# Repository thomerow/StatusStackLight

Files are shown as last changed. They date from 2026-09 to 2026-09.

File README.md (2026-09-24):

# StatusStackLight

An industrial stack light with five lamps, driven by an ESP32-S3 in a 3D-printed base –
dimmable, blinking and pulsing, via an HTTP API and a web interface on the local network. In
everyday use it shows what the running Claude Code sessions are doing right now – directly on
the local network, or through a relay server from anywhere.

<p align="center">
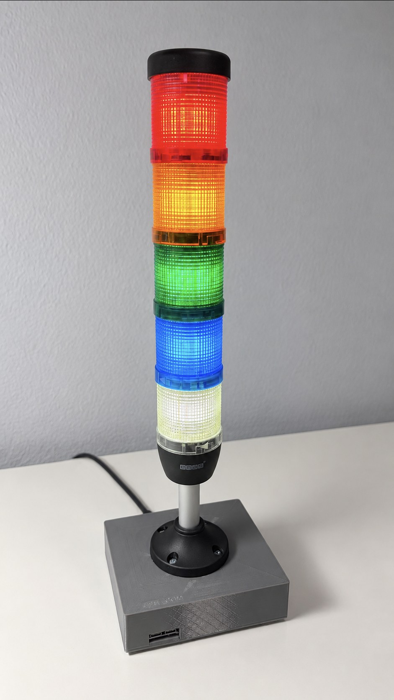
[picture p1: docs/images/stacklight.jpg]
The stack light with all five lamps lit on its 3D-printed base
  
</p>

## The four parts

| Folder | Contents |
|---|---|
| [`enclosure/`](enclosure/OpenSCAD/README.md) | Parametric base in OpenSCAD: carries the stack light and houses all the electronics. Print-ready STL files, print recommendations, assembly order. |
| [`firmware/`](firmware/README.md) | PlatformIO firmware for the ESP32-S3: PWM drive with effects, WiFi setup via captive portal, web interface, [HTTP API](firmware/API.md). |
| [`claude-code/`](claude-code/README.md) | PowerShell script that brings the state of Claude Code sessions to the stack light via hooks. |
| [`relay/`](relay/README.md) | Optional ASP.NET Core server between hooks and stack light: combines the sessions of several computers, the stack light polls it – no shared network needed. Admin interface for API keys, event rules and appearance. |

The parts build on each other but can also be used on their own: the firmware does not need
the base, the API is open to any client, not just the hook script, and the relay is only
needed when computer and stack light are not on the same network.

## Hardware

| Component | |
|---|---|
| Stack light | 5 lamps (white, blue, green, orange, red), 12 V LED modules, flange with 4 × M4 on a 55 mm bolt circle |
| Microcontroller | ESP32-S3 DevKitC-1 **N16R8** (16 MB flash, 8 MB octal PSRAM) |
| Driver | 8-channel MOSFET module, active LOW; 5 channels used |
| Power | USB-C PD trigger board (requests 12 V) → Mini560 buck → 3.3 V into the ESP32's 3V3 pin |
| Base | 138.8 × 120.8 × 35.8 mm, PETG or PLA+, heat-set inserts 4 × M3 and 4 × M4 |

<p align="center">
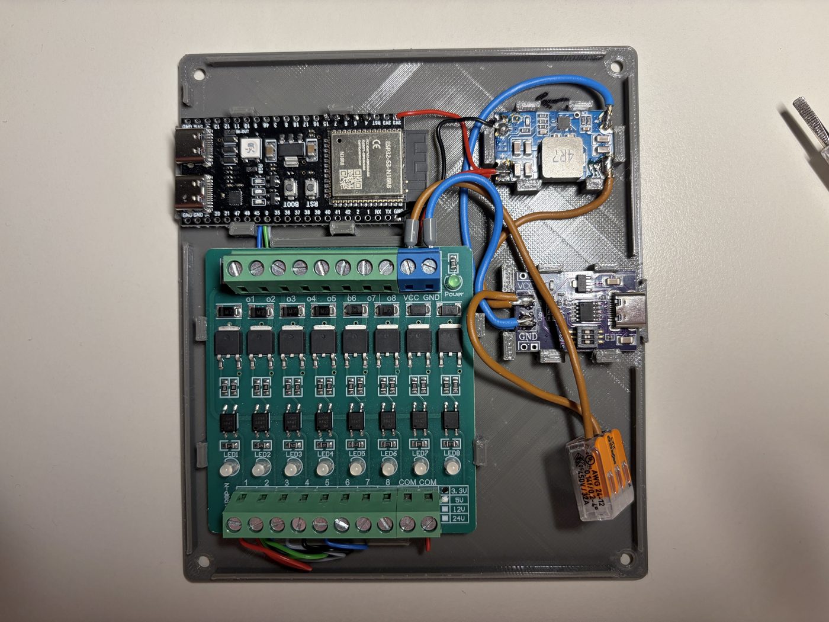
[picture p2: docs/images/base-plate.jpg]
The populated base plate seen from above: 8-channel MOSFET module, ESP32-S3, Mini560 and PD trigger board, each held by clips
  
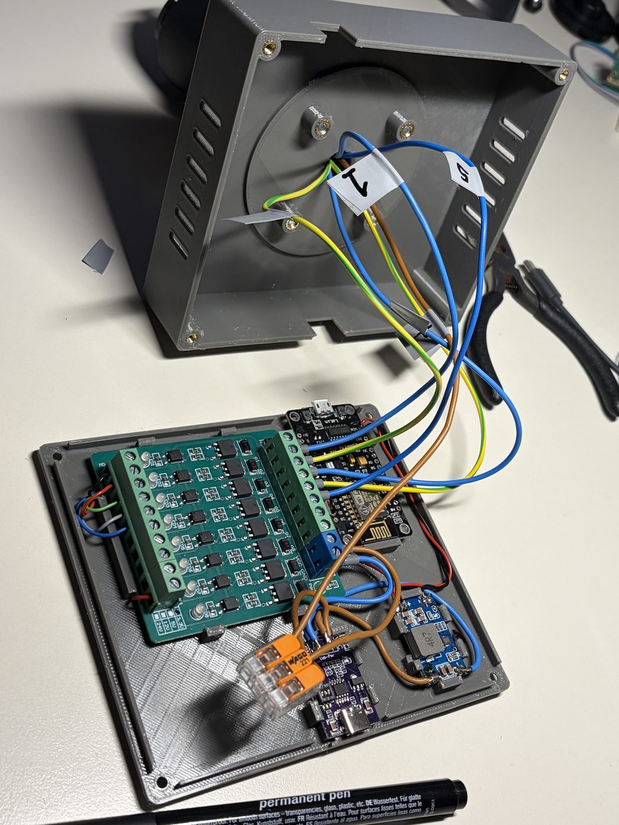
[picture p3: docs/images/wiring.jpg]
The main body standing on its lid with the lamp cables coming through the feed-through, next to it the populated base plate
  
  <br><em>Everything sits on the base plate, held by printed clips – no screws. The five lamp
  cables come through the feed-through in the lid.</em>
</p>

Pin assignment, dimensions and details are in the READMEs of
[`enclosure/`](enclosure/OpenSCAD/README.md) and [`firmware/`](firmware/README.md).

## Quick start

1. **Print:** `enclosure/OpenSCAD/body.stl` and `base.stl`, support-free, see the
   [print recommendations](enclosure/OpenSCAD/README.md#print-recommendations).
2. **Assemble and wire** following the
   [assembly order](enclosure/OpenSCAD/README.md#assembly-order).
3. **Flash:** in `firmware/` with [PlatformIO](https://platformio.org/) `pio run -t upload`,
   see [Building and flashing](firmware/README.md#building-and-flashing).
4. **Set up WiFi:** on first start the device opens the access point
   `StatusStackLight-XXXX`; the setup page appears by itself, see
   [WiFi setup](firmware/README.md#wifi-setup).
5. **Try it out:** `http://statusstacklight.local/` in the browser – every lamp can be
   switched there individually with all its parameters.
6. Optional: set up the **Claude Code display**, see [`claude-code/`](claude-code/README.md).
7. Optional: run the **relay** on a server, see [`relay/`](relay/README.md), and switch the
   stack light and the hook script to relay mode.

## License

[MIT](LICENSE) – for firmware, scripts, relay, enclosure model and documentation.

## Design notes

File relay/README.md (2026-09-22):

# StatusStackLight – Relay

A small ASP.NET Core service that sits between the Claude Code hooks and the stack light, so
computer and stack light no longer need to be on the same network:

```
 Claude Code ──hook──▶ stacklight.ps1 ──POST /api/v1/events──▶ ┌────────┐
 (any number of                                                │ relay  │ ◀── admin interface
  computers)                                                   └────────┘     (browser)
                                                                   ▲
 stack light ──────────── GET /api/v1/lamps (long poll) ───────────┘
```

- The **hook script** reports every event (`SessionStart`, `Approval`, `Stop`, …) with its
  session ID – in [relay mode](../claude-code/README.md#relay-mode).
- The **relay** keeps the sessions of all computers and turns them into the image of the five
  lamps: which state wins, when green falls back to white, when a crashed session is
  forgotten, when the warning flash ends.
- The **stack light** fetches that image by long polling – in
  [relay mode](../firmware/README.md#relay-mode). A change arrives within a fraction of a
  second; while nothing happens, there is one request every 25 seconds.
- The **admin interface** sets what each event does and how each state looks, and manages
  the API keys. Out of the box it does exactly what the script does in LAN mode.

The relay needs no inbound connection to your home network – the stack light always calls
out.

## Admin interface

| Page | |
|---|---|
| Dashboard | what the stack light shows right now (animated), open sessions, polling stack lights, test events |
| Display | per state (ready, done, working, asking, waiting, error, warning flash): which lamps, effect, brightness, rate, duty cycle – with a live preview |
| Events | per hook event: which session state it sets, whether it sets or clears the error, an optional condition, warning flash |
| Settings | priority of the main states, done → ready after, forget sessions after, flash duration, long poll duration |
| Keys | create, rename, delete API keys |

Every page has *Reset to defaults*. The defaults live in one place,
[`Domain/Defaults.cs`](src/StatusStackLight.Relay/Domain/Defaults.cs).

**Keys** have a role: *lamp* keys may only fetch the display, *client* keys may only report
events. Give every stack light and every computer a key of its own – then a lost laptop is
one click away from being locked out. A key is shown exactly once when it is created; the
relay only stores its SHA-256 hash.

**The admin password** is set on the server, never over the web: an admin interface on the
internet that lets its first visitor choose the password is an open door until someone gets
there first. Login attempts are limited to ten per minute and address.

## Trying it locally

Requires the [.NET 10 SDK](https://dotnet.microsoft.com/download).

```powershell
cd relay/src/StatusStackLight.Relay
dotnet run -- set-password        # once: the admin password
dotnet run                        # http://localhost:5080
```

Create a *client* key and a *lamp* key under **Keys**. Then:

- **Hook script:** `setx STACKLIGHT_RELAY_URL "http://<this computer's IP>:5080"` and
  `setx STACKLIGHT_RELAY_KEY "ssl_…"` (the client key), restart Claude Code.
- **Stack light:** in its web interface under *Relay*: address
  `http://<this computer's IP>:5080`, the lamp key, relay mode on.

On Windows the firewall asks the first time whether `StatusStackLight.Relay.exe` may accept
connections – allow it for private networks, otherwise the stack light cannot reach it.

Data (database and login keys) ends up in `App_Data/` next to the project.

## Running it on a server

The following assumes a Linux server with nginx and a host name, e.g. `relay.example.org`.

**1. Publish** – self-contained, so the server needs no .NET runtime:

```bash
dotnet publish src/StatusStackLight.Relay -c Release -r linux-x64 --self-contained -o publish
```

For an ARM server (e.g. a Raspberry Pi): `-r linux-arm64`.

**2. Install:**

```bash
sudo useradd --system --no-create-home --shell /usr/sbin/nologin statusstacklight
sudo mkdir -p /opt/statusstacklight-relay
sudo rsync -a --delete publish/ /opt/statusstacklight-relay/     # or scp
sudo chmod +x /opt/statusstacklight-relay/StatusStackLight.Relay

sudo cp deploy/statusstacklight-relay.service /etc/systemd/system/
sudo systemctl daemon-reload
sudo systemctl enable --now statusstacklight-relay
```

**3. Set the admin password** – as the service user, with the same data directory as the
service:

```bash
cd /opt/statusstacklight-relay
sudo -u statusstacklight env DataDirectory=/var/lib/statusstacklight-relay \
     ./StatusStackLight.Relay set-password
```

The command can be run again at any time to change the password; logins stay valid.

**4. nginx with HTTPS:** adapt [`deploy/nginx.conf.example`](deploy/nginx.conf.example),
then `sudo certbot --nginx -d relay.example.org`. Important for long polling:
`proxy_read_timeout` must be longer than the relay's long poll duration (25 s by default);
the example uses 60 s.

The address for hook script and stack light is then `https://relay.example.org`.

**Updates:** publish again, copy over, `sudo systemctl restart statusstacklight-relay`. The
database is migrated automatically at startup. Stack lights reconnect by themselves within a
few seconds; sessions are held in memory only and come back with each session's next hook.

### Without nginx

The relay can also listen on a port directly: set `Urls=http://0.0.0.0:5080` in the systemd
unit and open the port in the firewall. **Then the API keys and the admin password travel over
the internet in plain text** – only do that for a test, or give Kestrel a certificate of its
own (see the ASP.NET Core documentation on `Kestrel:Certificates`).

### Configuration

Environment variables (or `appsettings.json`):

| Name | Default | |
|---|---|---|
| `Urls` | `http://*:5080` | address and port to listen on |
| `DataDirectory` | `App_Data` | database `relay.db` and the key ring for the login cookie `keys/`; relative to the working directory |
| `PathBase` | – | sub-path when served under e.g. `https://example.org/stacklight/` |

**Backup:** the data directory is all there is. Losing `keys/` only logs you out; losing
`relay.db` loses the API keys, the configuration and the admin password.

## API

For stack lights and scripts – see **[API.md](API.md)**.

## Development

```powershell
cd relay
dotnet test                                   # domain logic, API, admin pages
dotnet tool restore                           # once, for dotnet-ef
dotnet dotnet-ef migrations add <Name> -p src/StatusStackLight.Relay -o Data/Migrations
```

```
src/StatusStackLight.Relay/
  Domain/     display logic: sessions, event rules, lamp image, defaults – no ASP.NET
  Data/       SQLite via EF Core: API keys and the configuration (as JSON per section)
  Api/        JSON API, API key authentication, stack light registry
  Pages/      admin interface (Razor Pages)
  Services/   timer for time-driven transitions, admin password
  wwwroot/    CSS and the small script for preview and dashboard
tests/        xUnit: engine, validation, API, admin pages
deploy/       systemd unit, nginx example
```

**How the image comes about** – a port of `Get-MainState` and `Get-Lamps` from
[`stacklight.ps1`](../claude-code/stacklight.ps1):

1. Every event changes its session according to its rule (state, error flag).
2. Of the sessions, exactly one main state wins by priority: waiting > asking > working >
   done > ready. Done only counts while it is fresh (5 min); after that the session counts as
   ready. Sessions without events for an hour are forgotten.
3. On top: error (if any session has one), then the warning flash (for 1.2 s after `Danger`).
4. Lamps that are off still carry the parameters of their state, so the stack light's web
   interface shows sensible values.

The image carries a **version** that only changes when the image changes. A stack light
polls with the version it shows and gets an answer as soon as there is a different one –
a burst of events that ends where it started costs it nothing.

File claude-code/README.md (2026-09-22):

# StatusStackLight – Claude Code session display

`stacklight.ps1` shows on the stack light what the running
[Claude Code](https://claude.com/claude-code) sessions are doing right now: whether Claude
is working, is done, has a question or is waiting for an approval. The script hooks into
Claude Code and drives the stack light through the [firmware's HTTP API](../firmware/API.md) –
or, in [relay mode](#relay-mode), through a relay server the stack light polls.

## What the stack light shows

| Lamp | State | Appearance |
|---|---|---|
| white | ready – session open, nothing going on | breathes very slowly, 0.15 Hz, up to 30 % |
| green | done – just finished | steady, 45 %, for five minutes |
| blue | working | pulsing, 0.3 Hz, 70 % |
| orange | a question for you | steady, 40 % |
| orange | waiting for an approval | blinking, 1.2 Hz, 40 % |
| red | error | steady, 100 %, latched until the next prompt |
| red | dangerous command (`rm -rf`, `git push --force`, …) | short flash, 6 Hz, on top of the other state |

Exactly one of ready/done/working/question/approval is lit (priority from right to left);
red sits on top independently.

## Setup

**Requirements:** Windows with [PowerShell 7](https://github.com/PowerShell/PowerShell)
(`pwsh.exe`) and a stack light running the firmware from this repo on the same network.

1. **Address of the stack light.** The script talks to it at `http://statusstacklight`. If
   your network does not resolve that name, set the environment variable `STACKLIGHT_URL`,
   for example to `http://statusstacklight.local` or `http://192.168.178.72`.
2. **Add the hooks.** Copy the `hooks` block from [`hooks.example.json`](hooks.example.json)
   into `~/.claude/settings.json`. In every entry, replace the placeholder
   `C:\path\to\StatusStackLight\claude-code\stacklight.ps1` with the actual path, and if
   PowerShell 7 lives elsewhere, `command` as well.
3. **Try it out** without waiting for a hook:

   ```powershell
   $s = 'C:\path\to\StatusStackLight\claude-code\stacklight.ps1'
   & $s -Event Status      # shows what the stack light should show, without switching anything
   & $s -Event SelfTest    # the firmware's channel sweep, then back to the actual state
   & $s -Event AllOff
   ```

The script keeps its state under `~/.claude/stacklight/` (one file per session, plus
`_timer.json` and `_error.log`). It always exits with exit code 0 – an unreachable stack
light never holds up Claude Code; errors end up in `_error.log`.

## Relay mode

Without a relay, computer and stack light must be on the same network. With the
[relay](../relay/README.md), a small server anywhere on the internet, they need not: the script
reports its events there, and the stack light fetches the result. Sessions on several
computers then show up on the same stack light.

Set two environment variables for the user that runs Claude Code, with a key of the role
*client* from the relay's admin interface, and restart Claude Code:

```powershell
setx STACKLIGHT_RELAY_URL "https://relay.example.org"
setx STACKLIGHT_RELAY_KEY "ssl_…"
```

The hooks stay exactly as they are. As soon as both variables are set, the script sends every
event as one `POST /api/v1/events` to the relay instead of switching the stack light itself;
without them it works in LAN mode as before. `-RelayUrl` and `-RelayKey` override the
variables, for example to try it out:

```powershell
& $s -Event Status -RelayUrl https://relay.example.org -RelayKey ssl_…
```

In relay mode, the appearance and the event rules are set in the relay's admin interface –
the `$Display` table in the script only applies to LAN mode. Two things stay local:

- **The dangerous-command check.** For `Danger` the script checks the command text itself and
  only reports `Danger` – the command never leaves the computer.
- **The `ToolDone` shortcut.** `PostToolUse` fires after every tool call; the script only
  reports it while the session is waiting or asking, the condition of the relay's default
  rule. For this it keeps its session files as before.

`SelfTest` talks to the stack light directly and only works in LAN mode. `AllOff` makes the
relay forget all sessions, including those of other computers.

## How it works

The hooks deliver **events**, the stack light shows a **state**. Every session stores its
state as a file under `~/.claude/stacklight/`; from these the script computes what the lamps
show and sets it in **one** `POST /api/lamps` – completely on every event, even if nothing
has changed. That way the next hook heals any deviation, whether caused by a restart of the
stack light, the web interface or curl. Several parallel sessions therefore do not switch
each other off, and a crashed session is forgotten after an hour without events.

| Hook | Matcher | Event in the script |
|---|---|---|
| `SessionStart` | – | `SessionStart` |
| `UserPromptSubmit` | – | `UserPromptSubmit` |
| `Notification` | `permission_prompt` | `Approval` |
| `Notification` | `elicitation_dialog\|elicitation_url_dialog\|agent_needs_input` | `Question` |
| `PreToolUse` | `ExitPlanMode` | `Approval` |
| `PreToolUse` | `AskUserQuestion` | `Question` |
| `PreToolUse` | `Bash`, with `if` on dangerous commands | `Danger` |
| `PostToolUse` | `*` | `ToolDone` |
| `Stop` / `StopFailure` | – | `Stop` / `StopFailure` |
| `SessionEnd` | – | `SessionEnd` |

The script still accepts `Freigabe` and `Rueckfrage`, the former German names of `Approval`
and `Question`, so older hook configurations keep working.

**Red only when it matters.** `PostToolUseFailure` is deliberately not wired up, although the
script understands it as `-Event ToolFailure`. Failed tool calls are part of normal work – a
search without a match, a test that is meant to fail – and Claude usually handles them by
itself. Red for each of them would come so often that you stop looking, and then it is
overlooked in the one case that counts. Red stays reserved for a response that ended in an
error (`StopFailure`) and for the warning flash.

**Orange only when Claude needs you.** The Notification hook has matchers on the
notification type: `permission_prompt` is an approval (blinking), `elicitation_dialog`,
`elicitation_url_dialog` and `agent_needs_input` are questions (steady). The idle notice
after a minute without input (`idle_prompt`) is deliberately left out – it would turn every
green into orange after 60 s. In addition, the tools `ExitPlanMode` (approval) and
`AskUserQuestion` (question) trigger directly via `PreToolUse`. The distinction is made
through separate hook entries with the events `Approval` and `Question`, not through fields
of the hook input: their structure is not documented for Notification.

A question that Claude simply asks as text at the end of its response cannot be detected by
the hooks – then the stack light shows green, as for every finished response.

**Orange goes off again** as soon as the approved tool has run or the question has been
answered: `PostToolUse` calls the script with `ToolDone`, and it switches back to blue.
Without that, orange would stay lit until the end of the response, because an approval is
not a new prompt. Limitation: Claude Code does not report a moment of "approval granted" –
during a long build it therefore blinks until the approved command has finished.
`PostToolUse` fires after every tool call; if the session is not waiting, the script exits
immediately without a request to the stack light.

**Green falls back to white after five minutes** – "freshly done" is different information
from "has been sitting there a while". Since no hook may fire for a long time after that,
`Stop` starts a hidden straggler that waits out the time and recomputes once. Only one ever
runs; a new `Stop` ends the previous one.

**Brightness:** White is by far the brightest lamp and needs much less percent to look
equally bright – undimmed it is unbearable as a steady light. When breathing, the percentage
is the peak: the breath runs from 0 up to there, and due to gamma correction the lower third
is practically dark. That is why the peak at 30 % is well above what white would need as a
steady light. Orange at full brightness is glaring up close and therefore runs dimmed; the
attention comes from the blinking, not from the brightness. All values are in the
`$Display` table at the top of the script.

**Warning flash only for real matches.** The `if` conditions in the `PreToolUse` hook
(`Bash(rm -rf *)` etc.) are only a rough pre-filter: commands that Claude Code cannot parse
cleanly – loops, `$(…)`, heredocs – are let through to be safe; even
`for i in 1; do echo "$(echo harmless)"; done` passes the pre-filter. The script therefore
checks the actual command text once more itself.

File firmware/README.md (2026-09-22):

# StatusStackLight – Firmware (ESP32-S3)

Firmware for the 5-lamp stack light. It provides an HTTP JSON API for driving the lamps and
a web interface that lets you play through every parameter of each lamp individually.

The enclosure and mechanics live in [`../enclosure`](../enclosure/OpenSCAD/README.md), the
display of Claude Code sessions in [`../claude-code`](../claude-code/README.md). The
[README in the root directory](../README.md) gives an overview of the whole project.

## What the lamps can do

Each lamp has a master switch, a brightness and a timing behaviour:

| Field | Range | Meaning |
|---|---|---|
| `on` | `true` / `false` | master switch |
| `brightness` | 0…100 % | peak brightness, gamma corrected |
| `effect` | `steady`, `blink`, `pulse` | constant / hard blinking / soft pulsing |
| `frequency` | 0.1…20.0 Hz | rate for `blink` and `pulse` |
| `duty` | 1…99 % | `blink` only: share of the period during which the lamp is lit |

`on` is deliberately separate from the effect. Turn a blinking lamp off and on again and you
get it back blinking – brightness and effect survive being switched off.

Several lamps with the same frequency blink in sync; the effect engine uses a common time
base for all five.

How to set these fields is described in [API.md](API.md).

## Hardware

| Item | Value |
|---|---|
| Board | ESP32-S3 DevKitC-1, **N16R8** (16 MB flash, 8 MB octal PSRAM) |
| Driver | 8-channel MOSFET module, low side, **active LOW** (GPIO to ground = lamp on) |
| Lamps | 12 V LED modules |
| Power | USB-C PD trigger board (12 V) → Mini560 buck → 3.3 V into the ESP32's 3V3 pin |

### Channel mapping

| Channel | GPIO | Colour | API ID |
|---|---|---|---|
| 1 | 4 | white | `white` |
| 2 | 5 | blue | `blue` |
| 3 | 6 | green | `green` |
| 4 | 7 | orange | `orange` |
| 5 | 15 | red | `red` |

This mapping was verified against the assembled stack light on 2026-09-21.

After rewiring or replacing a lamp, it can be checked again with the
[channel sweep](#diagnostics). If it no longer matches, swap the lines of the `LAMPS[]`
table in `include/config.h` – nothing else.

## WiFi setup

Credentials are stored in NVS, not in the source. If the device finds none there – freshly
flashed, on a different board or after `POST /api/reset` – it opens an open access point
itself:

1. The access point **`StatusStackLight-XXXX`** appears in the WiFi list (`XXXX` = the last
   two bytes of the MAC address, also printed on the serial console).
2. Connect – the setup page opens by itself as a captive portal. If not:
   `http://192.168.4.1/setup`.
3. Choose a network, enter the password, save. The device **tries the credentials first**
   and only stores them if the connection succeeds – a typo does not lock you out. That is
   why the response takes up to 20 seconds.
4. After that it is reachable at **`http://statusstacklight.local/`** (or at the IP the
   setup page reports – Android does not resolve `.local` reliably).

If the connection drops during operation, the device keeps retrying on its own; the lamps
keep showing their last state meanwhile. If it stays unsuccessful for more than two minutes,
the setup AP opens again. The API is then reachable at the AP address; changes to the lamps
are stored but only shown after the next connection – until then, orange pulses (see
below).

### Boot display

When plugged in, the stack light shows how far along it is instead of showing the stored
lamp state right away:

| Display | Meaning |
|---|---|
| blue pulsing (1 Hz) | connecting to the stored WiFi network |
| green lit for one second, then briefly dark | connected – then the stored lamp state appears |
| orange pulsing slowly | setup AP open: no WiFi stored or none reachable |
| red pulsing slowly, dim | relay mode: no contact to the relay for a minute, see [Relay mode](#relay-mode) |

Orange stays until a WiFi network has been entered via the setup AP; during the connection
attempt blue pulses again, and on success the green signal follows. Blue deliberately pulses
faster than "Claude is working" (0.3 Hz). If the connection only drops briefly during
operation, no display appears – the Claude status stays visible. Rate, flash duration and
brightness are set in `config.h` under `DISPLAY_*`.

## Relay mode

Normally the stack light waits on the local network for the hook script to switch it. In
**relay mode** it fetches its state itself from a [relay server](../relay/README.md) on the
internet instead – then the computers running Claude Code need not be on the same network,
and several of them can feed the same stack light.

Set it up at the bottom of the web interface under **Relay**: switch on relay mode, enter the
relay's address (for example `https://relay.example.org` or `http://192.168.178.10:5080`) and
a key with the role *lamp* from the relay's admin interface, save. The key is stored in NVS
(namespace `ssl-relay`) and never shown again; to keep it, leave the field empty.

- **Long polling:** the stack light asks the relay for the current image and names the
  version it shows. The relay holds the request until something changes, at the latest
  25 seconds (`RELAY_WAIT_S`). A change thus arrives within a fraction of a second, and while
  nothing happens there is one request every 25 seconds.
- **HTTPS** works with certificates from Let's Encrypt: the firmware trusts the roots ISRG
  Root X1 and X2 (`include/relay_ca.h`). For another CA, add its root certificate there.
  Without TLS, the key travels over the network in plain text.
- **The local API stays usable** – handy for trying things out. What is set locally stays
  until the relay's next change overwrites it. The web interface shows a banner in relay mode.
- **Without contact to the relay** for more than a minute (`RELAY_LOST_AFTER_MS`), **red
  pulses slowly and dimly** – the display is out of date, nothing is broken. Retries back off
  from 2 to 30 seconds; as soon as the relay answers, its image appears. The web interface
  names the last error (wrong key, address unreachable, …).

Over the API: `POST /api/config/relay`, see [API.md](API.md#post-apiconfigrelay).

## Diagnostics

At the bottom of the web interface: **Channel sweep**. It turns channels 1 to 5 on one at a
time for one second each and reports on the serial console which colour is expected – the
quickest way to see each channel on its own after replacing a lamp or when a loose contact
is suspected:

```
[sweep] channel 1  GPIO  4  expected: white
[sweep] channel 2  GPIO  5  expected: blue
...
```

Afterwards the previous state is restored. Also available via the API: `GET /api/sweep`.

If a channel misbehaves:

- **One lamp stays dark while the others work** – the fault is behind the GPIO. To narrow it
  down, measure at the MOSFET output while the sweep is on that channel.
- **The wrong lamp lights up** – swap the lines in `LAMPS[]` in `include/config.h`.
- **The stack light flashes briefly while booting** – the MOSFET module lacks pull-ups on its
  control inputs; add 10 kΩ to 3.3 V on each. The firmware drives the GPIOs to the off level
  first thing, but cannot bridge the time before that.
- **Everything switches exactly the wrong way round** – `LAMP_ACTIVE_LOW = false` in
  `config.h`.

## API

The complete description of all endpoints with requests, real responses, error codes and
examples in curl and PowerShell is in **[API.md](API.md)**.

A quick start:

```bash
curl http://statusstacklight.local/api/status                     # everything at a glance
curl 'http://statusstacklight.local/api/lamps/red/on?brightness=50' # turn red on
curl -X PATCH http://statusstacklight.local/api/lamps/orange \
     -H 'Content-Type: application/json' -d '{"effect":"blink","frequency":2}'
```

Invalid values are rejected with `400` and a plain-text message instead of being silently
clamped – a silently halved brightness sends you looking in the wrong place when debugging.

## Building and flashing

```powershell
pio run                 # build
pio run -t upload       # build and flash
pio device monitor      # serial console, 115200 baud
```

Two environments, depending on which USB-C port of the DevKitC-1 you use (labelled `USB` and
`COM` on the enclosure lid):

| Environment | Port | |
|---|---|---|
| `uart` (default) | **COM** | Recommended. The port survives reset and flashing, and you also see the output of the ROM bootloader. |
| `usb` | **USB** | Native USB port. Works, but the COM port disappears on every reset. |

```powershell
pio run -e usb -t upload
```

The first build downloads the platform and the Xtensa toolchain – that takes a while and
needs internet access.

**Power while flashing:** The Mini560 feeds 3.3 V directly into the 3V3 pin, bypassing the
board's voltage regulator. If USB is plugged in as well, two sources drive the same rail –
Espressif explicitly calls the two supply paths "mutually exclusive". For a short flash this
usually works in practice; the clean way is to disconnect the 3.3 V line first (ground may
stay). The board is a clone with a CH343 instead of a CP2102N, so protection diodes on the
USB ports are not guaranteed.

### Two things that are this way on purpose

**`build_dir` points outside the project** (`C:/pio/StatusStackLight`). For one, non-ASCII
characters in paths are explicitly unsupported by PlatformIO, and a build directory outside
the project keeps that independent of where the project lives. For another, `.pio/build` is
around ten thousand files – in a Dropbox folder that means constant syncing and now and then
a locked file in the middle of a build.

**`board_build.arduino.memory_type = qio_opi`** matches the ESP32-S3-**WROOM-1** N16R8 (quad
flash, octal PSRAM). The similarly named WROOM-**2** N16R8**V** has 1.8 V octal flash and
would need `opi_opi` plus `flash_mode = dout` – otherwise the board does not even boot. When
in doubt, read the marking on the module. The startup banner prints the PSRAM size; if it
shows zero bytes instead of about 8 MB, the setting is wrong.

### If the build fails

**`ModuleNotFoundError: No module named 'intelhex'`** while creating `bootloader.bin`: the
bundled esptool 4.9 needs this Python package, but PlatformIO's own environment does not
include it. Install it once:

```powershell
& "$env:USERPROFILE\.platformio\penv\Scripts\python.exe" -m pip install intelhex
```

**Strange errors when opening files**: first suspect non-ASCII characters in the path (see
`build_dir` above) before searching the source.

## Structure

```
API.md                  HTTP API: all endpoints with examples
platformio.ini          board, environments, libraries
include/config.h        pins, colours, limits, defaults  <- adjust things here
scripts/embed_web.py    pre-build: web/*.html -> include/web_assets.h (gzip)
web/index.html          control page (source)
web/setup.html          WiFi setup page (source)
src/main.cpp            setup/loop
src/lamps.*             LEDC, effect engine, gamma, inversion, system displays
src/lamp_state.*        state of a lamp, validation, JSON
src/lamp_store.*        last lamp state in NVS, survives restarts
src/wifi_portal.*       credentials, station connection, setup AP, captive portal
src/relay_client.*      relay mode: long polling in its own task
include/relay_ca.h      root certificates for HTTPS to the relay
src/api_server.*        HTTP routes
```

The web interface is gzipped during the build and embedded into the firmware image as a byte
array. The HTML files thus remain normal, editable files, while a single upload step is
still enough – no separate flashing of a file system that you are guaranteed to forget after
an OTA. `include/web_assets.h` is generated and listed in `.gitignore`.

### Why the effects run in their own task

The LEDC base frequency stays constant at 1 kHz; the effects only modulate the duty cycle.
That is handled by a FreeRTOS task at 100 Hz on **core 0**, while the web server runs in the
Arduino loop on core 1. This separation is why the synchronous `WebServer` from the Arduino
core is good enough: not even a hanging HTTP client can make the blinking stutter. This
spares the project a dependency on ESPAsyncWebServer and AsyncTCP along with their version
traps.

### State across restarts

The firmware remembers the state of all five lamps in NVS (namespace `ssl-lampen`, separate
from the WiFi credentials – `/api/reset` leaves it alone) and restores it at startup, before
the effect task starts. Without that, the stack light would stay dark after a power cut,
restart or flash until the next hook happens to send the target state – and if Claude is
waiting for input, none fires.

It only writes on a real change and only after 2 s of quiet (`STORE_DELAY_MS`). The hook
script sends the complete state on every event, mostly unchanged – that does not trigger a
write. A slider dragged in the web interface results in one write instead of twenty, and the
warning flash is over before it reaches the flash.

The restored state may be outdated – say, blue pulsing from a session that ended during the
power cut. The next hook corrects that.

The NVS namespaces (`ssl-lampen`, `ssl-wlan`) and keys keep their original German names, so
devices keep their stored state and credentials across firmware updates. The relay settings
live in `ssl-relay`.

### PWM base frequency

Fixed at **1 kHz** (`PWM_BASE_FREQUENCY` in `config.h`), not changeable at runtime. There is
little headroom anyway: the MOSFET module manages about 2 kHz because its gates are
discharged through a 10 kΩ pull-down, which makes turn-off sluggish. The ESP32 would not be
the limit – its LEDC block would reach 19.5 kHz at 12 bits.

Not to be confused with a lamp's `frequency` field: that is the blink or pulse rate
(0.1–20 Hz) and has nothing to do with the PWM carrier frequency.

## Displaying Claude Code sessions

Through hooks, the stack light shows the state of running Claude Code sessions. The script,
hook configuration and display scheme are in [`../claude-code`](../claude-code/README.md);
across networks through the relay, see [Relay mode](#relay-mode).

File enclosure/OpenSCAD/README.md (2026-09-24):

# StatusStackLight – Enclosure (OpenSCAD)

Parametric, 3D-printable enclosure that carries an industrial stack light and houses the
electronics: ESP32-S3 DevKitC-1 (N16R8), 8-channel MOSFET module, Mini560 buck converter
(12 V → 3.3 V) and a USB-C PD trigger board that requests 12 V from the power supply.

**The stack light has 5 lamps.** So only 5 of the 8 MOSFET channels are used; the other
three are deliberately left free. The 8-channel module is in there anyway because it was on
hand – at 68 × 72 × 16 mm it is the largest component and thus determines both the inner
dimensions and the inner height of the enclosure. If you want a smaller box, start there,
not with the microcontroller.

**Stage 1: two parts** – main body with integrated lid + removable base plate.

| File | Contents |
|---|---|
| `statusstacklight_enclosure.scad` | complete model, all dimensions as variables at the top of the file |
| `render.ps1` | generates STLs and preview images from the command line |
| `body.stl` / `base.stl` | exported printable parts (from the current parameters) |
| `preview/` | rendered previews |

Current outer dimensions: **138.8 × 120.8 × 35.8 mm** (interior 134 × 116 × 31 mm).

## Design principles

* **Coordinates:** `x = 0…inner_x` (left→right), `y = 0…inner_y` (front→back), `z = 0` is
  the parting plane = top of the base plate. All layout positions are given in these inner
  coordinates.
* **The base plate carries all the electronics.** It is populated outside the enclosure and
  then slid in vertically from below.
* **Flat top.** The lid is completely smooth on the outside – only the four M4 holes and the
  cable feed-through. A raised centering ring around the stack light base is still in the
  model as `light_centering_ring`, but **disabled**: the main body is printed standing on the
  lid, so the ring would be the only thing resting on the print bed, and the whole remaining
  lid surface would hang 1.2 mm in the air. The flange is centred by the four M4 screws on
  the 55 mm bolt circle anyway.
* **No screws for the boards.** Each board sits on four support pads; along one edge there
  are two rigid support ledges, along the opposite edge two springy snap clips with a 45°
  lead-in chamfer. Slide the board at an angle under the rigid side, press down on the
  opposite side – it snaps in.
* **Closure:** 4 corner bosses with M3 heat-set inserts (Ø 4.0 × 6 mm), M3 countersunk
  screws from below. The countersinks are **conical** (90° per DIN 7991), so the head rests
  flat on the cone flank instead of on an edge. The depth is computed from
  `countersink_angle` and `countersink_d` and not set separately – otherwise the cone no
  longer matches the screw head. A short cylindrical lead-in (`countersink_lead`, 0.3 mm) at
  the outer surface absorbs the elephant's foot of the first layer; the head thus sits about
  0.4 mm below the surface. With a 2.4 mm floor, 0.7 mm of material remains below the
  countersink – the model computes this and warns if it gets too thin.

### USB-C PD trigger board – strain relief

The port sits in the middle of a 20 mm edge and passes through the middle of the front
wall:

* The wall opening (13.5 × 7.5 mm) is **open downwards to the parting plane**, so the
  populated base plate slides in without collisions – and it prints without a bridge.
* A **connector collar** on the base plate fills the slot below the opening again and forms
  the lower edge of the visible opening.
* The port **protrudes 1 mm beyond the board edge** and thus dips into the wall opening
  itself.
* An **outer recess** (17 mm wide, 1.2 mm deep) thins the wall in front of the port.
  Together with the protrusion, only **0.2 mm of wall** remains in front of the port mouth –
  the plug seats practically flush and its full length engages. The model checks this at
  compile time (`usbc_gap`); the recess must not exceed `wall − usbc_protrusion`.
* **Force flow:** The **saddle** below the board's front edge takes downward forces, the
  clips hold upwards, the **stop rib** behind the board takes the plug-in force, and the
  front wall itself (the board edge rests against it left and right of the opening) holds
  against pulling out. The port's solder joints are not loaded in any direction.
* **The stop rib is split in two** (`usbc_rib_gap`, 10 mm): the PD board's solder eyes sit
  at the back centre, and the wires need a way out backwards there. What remains are two
  segments of 7 mm each at the back board corners. For the force flow that is no loss,
  rather the opposite – the plug-in force now goes into the corners instead of the middle,
  so the board is no longer loaded in bending. `usbc_rib_gap = 0` restores the continuous
  rib.

There is clearance all around: the port is guided, not clamped.

## Usage

Everything the repo contains is produced with one call – **without the OpenSCAD GUI**:

```powershell
.\render.ps1                 # body.stl, base.stl and all preview/*.png
.\render.ps1 -Only Stl       # only the printable parts
.\render.ps1 -Only Preview   # only the images (< 1 s per image)
```

The script finds `openscad.exe` by itself (otherwise `-OpenScad <path>`) and finally prints
the model's derived dimensions and collision checks:

```
Inner size  : 134 x 116 x 31 mm
Outer size  : 138.8 x 120.8 x 35.8 mm (flat lid)
USB-C port  : face y=-1  recess floor y=-1.2  remaining wall=0.2 mm  -> OK
Countersink : 90 degrees, depth 1.7 mm  remaining floor=0.7 mm  -> OK
Light bosses: bottom z=21  tallest assembly z=19  -> OK
```

For design work, open the file in the OpenSCAD GUI as usual; `part` switches between
`"both"`, `"body"`, `"base"` and `"explosion"`.

> Pitfall for your own scripts: `openscad.exe` is a GUI subsystem binary and returns
> **immediately** unless PowerShell consumes its output through a real pipeline – an
> assignment like `$log = & $OS @args 2>&1` does **not** wait for rendering to finish.
> `render.ps1` therefore reads through `| ForEach-Object { "$_" }` and additionally checks
> the timestamp of the written file.

`show_boards = true` shows the boards as transparent ghosts (`%`) – they are **not**
included in the render/STL.

## Dimensions

### Measured and confirmed

| Variable | Value | |
|---|---|---|
| `mosfet_h` | 16 | height of the MOSFET module incl. screw terminals |
| `light_base_d` | 70 | outer diameter of the stack light base; determines the lid reinforcement (base + 10 mm) on the inside |
| `light_bolt_circle_d` | 55 | |
| `light_screw_n` | 4 | |
| `pd_w` × `pd_l` | 20 × 31.5 | USB-C PD trigger board |
| `usbc_protrusion` | 1.0 | protrusion of the port beyond the board edge |
| `buck_l` × `buck_w` × `buck_h` | 30 × 18 × 6 | Mini560 – replaces the LM2596, 13 mm shorter and 8 mm lower |
| `mcu_l` × `mcu_w` × `mcu_h` | 57.3 × 28.1 × 5.0 | ESP32-S3 DevKitC-1 N16R8; height = 1.6 board + 3.4 components |
| `mcu_antenna` | 6.3 | overhang of the module's antenna end beyond the board edge |
| `mcu_stop_above` | −0.2 | top of the end stop relative to the board top. Negative, so a tenth of print over-height does not lift the board's front edge; the stop still engages 1.4 of the 1.6 mm edge. |
| `mcu_standoff` | 3.0 | wires are fed into the solder eyes from above, so the solder joints protrude downwards |
| `mcu_usb_edge` / `mcu_com_edge` | 8.0 / 19.5 | port centres from the board edge that is on the **right** inside the enclosure |
| `light_cable_d` | 12 | central cable feed-through in the lid, fits the wires of the 5 lamps |

> **Convention:** all `*_h` are **total heights including the board**, as measured with
> calipers across the whole module. `*_standoff` is the distance of the board underside from
> the parting plane.

### Still open

| Variable | current | Note |
|---|---|---|
| `usbc_recess_d` | 1.2 | only 0.2 mm of headroom left (see above) |

After every change, a new export is enough – layout, enclosure height and all cutouts are
recomputed.

## Layout (inner coordinates)

| Assembly | Size | Area X / Y | Remarks |
|---|---|---|---|
| MOSFET 8-channel | 68 × 72 | 12…84 / 42…110 | Screw terminals face the left/right side walls, clips front/back. Only 5 channels used (5 lamps), 3 stay free. Tallest assembly – sets the inner height. |
| ESP32-S3 | 28.1 × 57.3 | 90…118.1 / 58.7…116 | Rotated 90°, both USB-C ports through the back wall. The module's antenna end overhangs the board edge up to y = 52.4 |
| Mini560 | 18 × 30 | 100…118 / 6…36 | Rotated 90°, front right zone; the clips grip the long edges, the solder pad edges stay free. Front **left** support ledge shifted, see below |
| PD trigger | 20 × 31.5 | 57…77 / 0…31.5 | Port exactly centred in the front wall (x = 67) |

The front left zone (x 12…50, y 0…40) stays free for wiring; the lamp cables run from the
MOSFET terminals to the cable feed-through in the lid.

<p align="center">
  The populated base plate seen from above: 8-channel MOSFET module, ESP32-S3, Mini560 and PD trigger board, each held by clips
  <br><em>The populated base plate. The ESP32's two ports point left (the back wall), the
  USB-C power input right (the front wall).</em>
</p>

### Special case: front left support ledge of the Mini560

On the left board edge of the Mini560 (top view of the base plate, USB-C input at the
bottom) a component sits flush with the edge – the support ledge cannot grip there. It
therefore moves **3 mm forward** (`buck_clip_fl_shift`) and is at the same time **4 instead
of 6 mm wide** (`buck_clip_fl_width`), because otherwise it would be in the way of the
solder joint of the plus input. That leaves 3.4 mm to the board's front edge.

| Clip | y | Width |
|---|---|---|
| left back | 27.6 | 6.0 |
| right back | 27.6 | 6.0 |
| right front | 14.4 | 6.0 |
| **left front** | **11.4** | **4.0** |

This is made possible by the optional parameters `clips_fixed` / `clips_spring` of
`board_holder()`: a list `[[position, width], …]` per edge. Without them, the symmetric
default applies (two clips at 28 % and 72 % of the edge length, each `clip_w` wide), so
individual clips can be placed around components without giving up the symmetry for all
other boards.

## Print recommendations

| Part | Orientation | Note |
|---|---|---|
| `body.stl` | **standing on the lid**, opening facing up | support-free: the flat lid surface rests fully on the bed, the connector slots that are open at the bottom then face up, and the chamfer of the cable feed-through is self-supporting as a 45° overhang |
| `base.stl` | flat, clips facing up | support-free; the countersinks face the print bed and are self-supporting at 45° |

* Layer height 0.2 mm, 3 perimeters (4 for the base plate, so the clips do not shear off),
  infill ≥ 25 %.
* Material: PETG or PLA+. PLA clips are more brittle – prefer PETG if you open it often.
* Heat-set inserts: 4 × M3 (Ø 4.0 × 6 mm) in the corner bosses, 4 × M4 (Ø 5.6 × 8 mm) in
  the stack light bosses. Alternatively `light_insert = false` for plain through holes.

## Pin assignment (ESP32-S3 DevKitC-1, N16R8)

| Channel | GPIO |
|---|---|
| 1 | **4** |
| 2 | **5** |
| 3 | **6** |
| 4 | **7** |
| 5 | **15** |

On the S3, PWM is no longer an issue: the LEDC block has 16 independent channels with up
to 14 bits, and **every** GPIO can be routed to it. Five dimmed lamps are thus a few lines
of code.

### Hands off

| Pin | Why |
|---|---|
| **35, 36, 37** | **Octal PSRAM.** The `R8` in N16R8 stands for 8 MB PSRAM, and it runs over exactly these three pins. On the quad variants they would be free – not on this one. |
| 26–32 | SPI flash of the module |
| 0, 3, 45, 46 | strapping pins (boot mode, JTAG source, VDD_SPI) |
| 19, 20 | native USB data lines (the "USB" port) |
| 43, 44 | UART0, the "COM" port |
| 38 (or 48) | on-board RGB LED. DevKitC-1 v1.1 uses GPIO38, v1.0 GPIO48; clones vary – when in doubt, try both. |

The five recommended pins are high-impedance during boot. The MOSFET module switches on at
LOW; if it has no pull-ups on its control inputs, add 10 kΩ to 3.3 V on each, otherwise it
may flicker briefly at power-on.

## Labels of the USB ports

The top of the lid carries engraved text (`mcu_text_depth` = 0.6 mm) above the two ports.
Rotated by 180°, it reads **from behind** – where you plug in.

The port centres are only 11.5 mm apart; at a legible font size "USB" and "COM" run into
each other. The labels are therefore spread apart from the centre via `mcu_text_spread`
(1.6). With only two ports, the left/right assignment stays unambiguous. `1.0` places them
exactly above the port centres – then `mcu_text_size` has to go below about 3.5 mm.

The model estimates the text width (0.95 × size per character, measured on the render) and
warns at compile time if it gets too tight. OpenSCAD cannot measure text.

The main body is printed standing on the lid – the text faces the print bed and comes out
clean, without supports.

## Assembly order

1. Press the inserts into the main body (M3 into the corner bosses, M4 into the stack light
   bosses from the inside).
2. Populate the base plate: press the MOSFET module, ESP32-S3, buck and PD board into the
   clips.
3. Wire up: USB-C PD → 12 V to the MOSFET module and the Mini560 input, output 3.3 V →
   ESP32-S3 (3V3 pin), GPIOs → MOSFET control inputs (pin assignment see above), common
   ground. The 3V3 pin feeds power bypassing the board's voltage regulator. According to
   Espressif, powering via 3V3 and via USB are mutually exclusive – so when flashing via USB
   it is better to disconnect the 3.3 V line (ground may stay).
4. Thread the lamp cables through the lid feed-through and connect them to the MOSFET
   terminals – 5 lamps, so 5 used channels plus a common return.
5. Insert the base plate vertically from below (all three USB-C ports slide into their
   slots) and fasten it with 4 × M3 countersunk screws.
6. Place the stack light in the middle of the lid and fasten it with 4 × M4 – the screws on
   the 55 mm bolt circle take care of the centering.

<p align="center">
  The main body standing on its lid with the lamp cables coming through the feed-through, next to it the populated base plate
  <br><em>Between steps 4 and 5: the main body rests on its lid, the lamp cables come through
  the feed-through. Labelling them before they disappear into the terminals saves a lot of
  tracing later.</em>
</p>

## Next stages

Cable strain relief at the USB-C input, dust protection/sealing, wall mounting tabs,
labelling, possibly a three-part design with a separate lid.

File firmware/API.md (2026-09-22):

# StatusStackLight – HTTP API

The stack light is controlled through a JSON API on the local network. This document
describes every endpoint with request and response. All responses shown are real responses
from the device; they are shortened where noted, and network names are replaced by example
names.

**Address:** `http://statusstacklight.local/` or the device's IP address. In the setup
access point it is `http://192.168.4.1/`.

**Ground rules:**

- Requests and responses are JSON (`Content-Type: application/json`).
- Every write request responds with the **resulting** state. The client never has to guess
  what arrived.
- Invalid values are **rejected, not clamped**. A request is either applied completely or
  not at all.
- There is no authentication. Anyone on the same network can switch the stack light and
  change the WiFi settings.
- CORS is open (`Access-Control-Allow-Origin: *`), so the API can also be used from a web
  page.

## Overview

| Method | Path | Body | Response | Purpose |
|---|---|---|---|---|
| GET | [`/api/status`](#get-apistatus) | – | device status + all lamps | everything at a glance |
| GET | [`/api/lamps`](#get-apilamps) | – | `{lamps: [...]}` | all five lamps |
| GET | [`/api/lamps/{id}`](#get-apilampsid) | – | lamp | one lamp |
| PATCH | [`/api/lamps/{id}`](#patch-apilampsid) | partial state | lamp | change individual fields |
| PUT | [`/api/lamps/{id}`](#put-apilampsid) | state | lamp | set the complete state |
| POST | [`/api/lamps`](#post-apilamps) | `{id: partial state, ...}` | `{lamps: [...]}` | several lamps at once |
| POST | [`/api/lamps/all`](#post-apilampsall) | partial state | `{lamps: [...]}` | the same change for all |
| GET | [`/api/lamps/{id}/on`](#shortcuts) | query | lamp | turn on |
| GET | [`/api/lamps/{id}/off`](#shortcuts) | query | lamp | turn off |
| GET | [`/api/lamps/{id}/toggle`](#shortcuts) | query | lamp | toggle |
| GET | [`/api/off`](#get-apioff) | – | `{lamps: [...]}` | all off |
| GET | [`/api/config`](#get-apiconfig) | – | configuration | hostname, WiFi mode |
| GET | [`/api/scan`](#get-apiscan) | – | `{networks: [...]}` | WiFi networks in range |
| POST | [`/api/config/wifi`](#post-apiconfigwifi) | `{ssid, password}` | `{ok, ssid, ip}` | set WiFi credentials |
| POST | [`/api/config/relay`](#post-apiconfigrelay) | `{enabled, url, key}` | relay settings | relay mode on/off, address, key |
| GET/POST | [`/api/sweep`](#get-apisweep) | – | `{ok, holdMs, channels}` | channel sweep |
| POST | [`/api/reset`](#post-apireset) | – | `{ok, message}` | delete WiFi credentials, restart |
| POST | [`/api/reboot`](#post-apireboot) | – | `{ok}` | restart |

`{id}` is the colour ID of a lamp (`white`, `blue`, `green`, `orange`, `red`) or its
channel number `1` to `5`. Case does not matter.

| Channel | ID | Colour |
|---|---|---|
| 1 | `white` | white |
| 2 | `blue` | blue |
| 3 | `green` | green |
| 4 | `orange` | orange |
| 5 | `red` | red |

## The lamp object

This is what a lamp looks like in every response:

```json
{
  "id": "orange",
  "channel": 4,
  "gpio": 7,
  "name": "orange",
  "color": "#f59e0b",
  "on": true,
  "effect": "blink",
  "brightness": 50,
  "frequency": 1.2,
  "duty": 55,
  "level": 50
}
```

**Writable fields:**

| Field | Type | Range | Default | Meaning |
|---|---|---|---|---|
| `on` | boolean | `true` / `false` | `false` | master switch |
| `effect` | string | `steady`, `blink`, `pulse` | `steady` | constant / hard blinking / soft pulsing |
| `brightness` | integer | 0…100 | 100 | peak brightness in %, gamma corrected |
| `frequency` | number | 0.1…20.0 | 1.0 | rate in Hz for `blink` and `pulse` |
| `duty` | integer | 1…99 | 50 | `blink` only: share of the period in % during which the lamp is lit |

`on` is separate from the effect. Turn a blinking lamp off and on again and you get it back
blinking: brightness, effect and rate survive being switched off.

Lamps with the same frequency blink and pulse in sync, because the firmware uses a common
time base for all of them. Sending a state again does not reset the phase.

**Read-only fields:**

| Field | Meaning |
|---|---|
| `id` | colour ID, fixed |
| `channel` | channel number 1…5 |
| `gpio` | GPIO pin on the ESP32 |
| `name` | display name in the web interface |
| `color` | display colour in the web interface |
| `level` | brightness in % actually being output at this moment – changes constantly with `pulse` and `blink` |

The read-only fields may be included in a write request and are then ignored. A lamp that
has been read can therefore be sent back unchanged.

`level` comes from the last tick of the effect engine, which computes every 10 ms. In the
response to a change it therefore still shows the value from before the change.

The state of all lamps survives a restart; the firmware stores it in flash.

## Reading

### GET /api/status

Everything at a glance: device, WiFi, PWM, channel sweep, display order and all lamps.

```json
{
  "device": "StatusStackLight",
  "firmware": "1.0.0",
  "uptime": 2192,
  "heap": 275504,
  "psram": 8385831,
  "wifi": {
    "mode": "sta",
    "ssid": "MyWiFi",
    "ip": "192.168.178.72",
    "rssi": -66,
    "connected": true,
    "hostname": "StatusStackLight.local"
  },
  "pwm": { "baseFrequency": 1000, "resolution": 12, "activeLow": true },
  "sweep": { "running": false, "channel": 0 },
  "display": "none",
  "relay": { "enabled": false, "connected": false, "version": 0, "lastContact": null, "lastError": null },
  "order": ["red", "orange", "green", "blue", "white"],
  "lamps": [ … five lamp objects … ]
}
```

| Field | Meaning |
|---|---|
| `uptime` | seconds since startup |
| `heap` | free heap in bytes |
| `psram` | PSRAM size in bytes; about 8 MB on the N16R8 |
| `wifi.mode` | `sta` = on the WiFi network, `ap` = setup access point open |
| `wifi.ssid` | in `sta` mode the connected network, in `ap` mode the name of the access point |
| `wifi.rssi` | signal strength in dBm; always 0 in `ap` mode |
| `pwm` | PWM carrier frequency in Hz, resolution in bits, whether the outputs are active LOW |
| `sweep.channel` | during the channel sweep the channel currently lit, 1…5, otherwise 0 |
| `display` | system display currently overlaying the lamp state: `connecting` (blue pulsing), `portal` (orange pulsing), `connected` (green signal), `relay-lost` (red pulsing dimly, relay mode without contact) or `none`. As long as it is not `none`, the lamps do not show the state from `lamps` – changes are still applied and appear afterwards. |
| `relay.enabled` | relay mode on |
| `relay.connected` | the last poll of the relay succeeded |
| `relay.version` | version of the image last fetched from the relay |
| `relay.lastContact` | seconds since the last successful poll, `null` if none yet. Up to 25 s is normal: the relay holds each request until something changes. |
| `relay.lastError` | plain-text reason of the last failure, `null` after a success |
| `order` | order of the lamps on the stack light from top to bottom |

```bash
curl http://statusstacklight.local/api/status
```

```powershell
$s = Invoke-RestMethod http://statusstacklight.local/api/status
"{0} {1}, {2}, {3} dBm" -f $s.device, $s.firmware, $s.wifi.ip, $s.wifi.rssi
```

### GET /api/lamps

```json
{ "lamps": [ … five lamp objects, channel 1 to 5 … ] }
```

### GET /api/lamps/{id}

```bash
curl http://statusstacklight.local/api/lamps/orange
curl http://statusstacklight.local/api/lamps/4          # the same lamp
```

```powershell
Invoke-RestMethod http://statusstacklight.local/api/lamps/orange
```

Response: a [lamp object](#the-lamp-object).

## Writing

### PATCH /api/lamps/{id}

Changes only the fields sent; all others stay as they are. The usual way to adjust a lamp.

```http
PATCH /api/lamps/orange
Content-Type: application/json

{"on": true, "effect": "blink", "frequency": 2}
```

```json
{"id":"orange","channel":4,"gpio":7,"name":"orange","color":"#f59e0b",
 "on":true,"effect":"blink","brightness":50,"frequency":2,"duty":55,"level":0}
```

`brightness` and `duty` stayed unchanged.

```bash
curl -X PATCH http://statusstacklight.local/api/lamps/orange \
     -H 'Content-Type: application/json' \
     -d '{"on":true,"effect":"blink","frequency":2}'
```

```powershell
$change = @{ on = $true; effect = 'blink'; frequency = 2 } | ConvertTo-Json
Invoke-RestMethod http://statusstacklight.local/api/lamps/orange -Method Patch `
                  -Body $change -ContentType 'application/json'
```

### PUT /api/lamps/{id}

Sets the complete state. Missing fields get their [default value](#the-lamp-object) – not
their previous one.

```http
PUT /api/lamps/orange
Content-Type: application/json

{"on": true}
```

```json
{"id":"orange","channel":4,"gpio":7,"name":"orange","color":"#f59e0b",
 "on":true,"effect":"steady","brightness":100,"frequency":1,"duty":50,"level":50}
```

Effect, brightness, rate and duty cycle are at their defaults afterwards, even though only
`on` was sent. If you only want to turn a lamp on, use `PATCH`.

### POST /api/lamps

Several lamps in one request. The key is the ID or channel number, the value a partial state
as with `PATCH`. Lamps not mentioned stay unchanged.

The firmware first validates all entries and then applies them all at once. If one is
invalid, no lamp changes. This is the right endpoint when several lamps together represent a
state, as in a status display.

```http
POST /api/lamps
Content-Type: application/json

{
  "blue":  {"on": true, "effect": "pulse", "frequency": 0.3},
  "green": {"on": false}
}
```

Response: `{"lamps": [...]}` with all five lamps.

```bash
curl -X POST http://statusstacklight.local/api/lamps \
     -H 'Content-Type: application/json' \
     -d '{"blue":{"on":true,"effect":"pulse","frequency":0.3},"green":{"on":false}}'
```

```powershell
$target = @{
    blue  = @{ on = $true; effect = 'pulse'; frequency = 0.3 }
    green = @{ on = $false }
} | ConvertTo-Json
(Invoke-RestMethod http://statusstacklight.local/api/lamps -Method Post `
                   -Body $target -ContentType 'application/json').lamps
```

### POST /api/lamps/all

The same partial change for all five lamps, for example to dim them all:

```http
POST /api/lamps/all
Content-Type: application/json

{"brightness": 20}
```

Response: `{"lamps": [...]}` with all five lamps.

### Shortcuts

Switching via `GET`, without a body. Formally unclean, because a `GET` changes something,
but handy for the browser address bar and simple scripts.

```
GET /api/lamps/{id}/on
GET /api/lamps/{id}/off
GET /api/lamps/{id}/toggle
```

The [writable fields](#the-lamp-object) may also come along as query parameters. They are
applied after switching:

```
GET /api/lamps/red/on?brightness=30&effect=pulse&frequency=0.5
GET /api/lamps/3/on                  (channel 3 = green)
```

Response: the [lamp object](#the-lamp-object) of the lamp that was switched.

```bash
curl 'http://statusstacklight.local/api/lamps/red/on?brightness=30'
curl http://statusstacklight.local/api/lamps/red/off
```

```powershell
Invoke-RestMethod 'http://statusstacklight.local/api/lamps/red/on?brightness=30'
Invoke-RestMethod http://statusstacklight.local/api/lamps/red/off
```

The shortcuts only accept `GET`; other methods get `405`.

### GET /api/off

Turns all lamps off. Effect, brightness and rate are kept.

Response: `{"lamps": [...]}` with all five lamps.

## WiFi and maintenance

### GET /api/config

```json
{
  "hostname": "StatusStackLight",
  "mode": "sta",
  "ssid": "MyWiFi",
  "apName": "StatusStackLight-88A8",
  "baseFrequency": 1000,
  "relay": { "enabled": true, "url": "https://relay.example.org", "keySet": true }
}
```

`ssid` is the configured network, even while the setup access point is open. `apName` is
the name under which that access point appears; the suffix is the last two bytes of the MAC
address. `relay` holds the [relay settings](#post-apiconfigrelay); the key itself is never
given out, only whether one is set.

### GET /api/scan

Scans for WiFi networks in range. The response takes a few seconds.

```json
{
  "networks": [
    { "ssid": "MyWiFi",      "rssi": -64, "encrypted": true },
    { "ssid": "Neighbour-5G", "rssi": -81, "encrypted": true }
  ]
}
```

A network with several access points may appear more than once.

### POST /api/config/wifi

Sets the WiFi credentials. This is meant for the setup page `/setup`, which uses this
endpoint.

```http
POST /api/config/wifi
Content-Type: application/json

{"ssid": "MyWiFi", "password": "secret"}
```

**The device tries the credentials before storing them.** It connects to the given network
and waits up to **20 seconds**. Only if that works do the credentials go into flash. The
response therefore only comes after the attempt.

Success – `200`:

```json
{"ok": true, "ssid": "MyWiFi", "ip": "192.168.178.72"}
```

`ip` is the address the device got on the new network.

Failure – `400`:

```json
{"error": "could not connect to 'MyWiFi' - check password and range"}
```

```json
{"error": "ssid must not be empty"}
```

**From the setup access point** – the intended way:

- The access point stays open during the attempt, so the request can be answered.
- On failure, the error message arrives and the access point stays open.
- On success, the device closes the access point. The response is often lost because the
  client loses its connection at exactly that moment. In this case an aborted request is
  therefore the sign of success. Afterwards the device is reachable on the new network at
  `http://statusstacklight.local/`.

**During normal operation** (device already on a WiFi network): the connection attempt drops
the existing connection, so the response usually does not arrive.

- On success, the device is on the new network afterwards.
- On failure, the device reconnects to the previous network, at the latest 20 seconds after
  the failed attempt. The stored credentials stay unchanged. Whether the attempt worked is
  shown afterwards by [`/api/config`](#get-apiconfig) in the `ssid` field.

The password is transmitted in plain text – HTTP is unencrypted, and the setup access point
is an open network.

```bash
curl -X POST http://192.168.4.1/api/config/wifi \
     -H 'Content-Type: application/json' \
     -d '{"ssid":"MyWiFi","password":"secret"}' \
     --max-time 30
```

```powershell
$credentials = @{ ssid = 'MyWiFi'; password = 'secret' } | ConvertTo-Json
Invoke-RestMethod http://192.168.4.1/api/config/wifi -Method Post `
                  -Body $credentials -ContentType 'application/json' -TimeoutSec 30
```

The timeout must be longer than the 20 seconds of the connection attempt.

### POST /api/config/relay

Switches [relay mode](README.md#relay-mode) on or off and sets the relay's address and API
key. In relay mode the stack light fetches its state from the relay by long polling; the
lamp endpoints above keep working, but the relay's next change overwrites what was set
locally.

```http
POST /api/config/relay
Content-Type: application/json

{"enabled": true, "url": "https://relay.example.org", "key": "ssl_..."}
```

| Field | Type | Meaning |
|---|---|---|
| `enabled` | boolean, required | relay mode on or off |
| `url` | string, optional | `http://` or `https://`, host, optional port and path, no query. A trailing slash is removed. Left out: stays as stored. |
| `key` | string, optional | API key with the role *lamp* from the relay. Left out: stays as stored. |

Response: the stored settings, as under `relay` in [`/api/config`](#get-apiconfig):

```json
{"enabled": true, "url": "https://relay.example.org", "keySet": true}
```

The object from `/api/config` may be sent back as it is; `keySet` is ignored. Turning relay
mode on needs an address and a key – stored or sent along:

```json
{"error": "relay mode needs an address and a key"}
```

Switching off takes effect at once: an answer that is still on its way is discarded. New
settings are used from the next poll on, which then fetches the complete image. If a poll is
still waiting at the relay, that is at the latest after about 25 seconds. Whether it worked is
shown by [`/api/status`](#get-apistatus) under `relay`.

```powershell
$relay = @{ enabled = $true; url = 'https://relay.example.org'; key = 'ssl_...' } | ConvertTo-Json
Invoke-RestMethod http://statusstacklight.local/api/config/relay -Method Post `
                  -Body $relay -ContentType 'application/json'

# off again, address and key stay stored
Invoke-RestMethod http://statusstacklight.local/api/config/relay -Method Post `
                  -Body '{"enabled":false}' -ContentType 'application/json'
```

### GET /api/sweep

Starts the channel sweep: channels 1 to 5 light up one at a time for one second each at full
brightness, then the firmware restores the previous state. Also accepts `POST`.

```json
{"ok": true, "holdMs": 1000, "channels": 5}
```

The response comes immediately. The sweep takes `channels × holdMs`, and
[`/api/status`](#get-apistatus) shows under `sweep` whether it is still running. Write
requests during the sweep are lost: at the end, the firmware restores the state from before
the sweep.

### POST /api/reset

Deletes the WiFi credentials and restarts. Afterwards the device opens the setup access
point. The lamp state stays stored.

```json
{"ok": true, "message": "wifi credentials cleared, rebooting"}
```

### POST /api/reboot

Restarts the device. After a few seconds it is reachable again, and the lamps show the state
from before the restart.

```json
{"ok": true}
```

## Errors

Errors always come as a JSON object with an `error` field, in plain text.

| Status | When | Example of `error` |
|---|---|---|
| 400 | value out of range | `field 'brightness' out of range: got 150, expected 0...100` |
| 400 | wrong type or value | `field 'effect' must be one of: steady, blink, pulse` |
| 400 | unknown field | `unknown field: 'colour'` |
| 400 | unknown query parameter | `unknown query parameter: 'colour'` |
| 400 | not valid JSON | `invalid json: InvalidInput` |
| 400 | empty body | `request body is empty` |
| 400 | error in `POST /api/lamps` | `lamp green: field 'duty' out of range: got 0, expected 1...99` |
| 404 | unknown lamp | `unknown lamp: purple` |
| 404 | unknown shortcut | `unknown action: blink (on, off, toggle)` |
| 404 | unknown endpoint | `unknown endpoint: /api/foo` |
| 405 | method not allowed | `method not allowed (GET, PATCH, PUT)` |
| 405 | shortcut not via GET | `shortcut on is GET only` |

An unknown lamp also returns the list of valid IDs:

```json
{"error": "unknown lamp: purple", "lamps": ["white", "blue", "green", "orange", "red"]}
```

Handling errors in PowerShell:

```powershell
try {
    Invoke-RestMethod http://statusstacklight.local/api/lamps/red -Method Patch `
                      -Body '{"brightness":150}' -ContentType 'application/json'
} catch {
    "Status : " + [int] $_.Exception.Response.StatusCode
    "Error  : " + ($_.ErrorDetails.Message | ConvertFrom-Json).error
}
```

```
Status : 400
Error  : field 'brightness' out of range: got 150, expected 0...100
```

The PowerShell examples work in PowerShell 7 and in Windows PowerShell 5.1.

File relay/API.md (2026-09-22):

# StatusStackLight Relay – HTTP API

The API for hook scripts and stack lights. The admin interface is not part of it; it uses
its own forms. All responses shown are real responses from the relay.

**Ground rules:**

- Requests and responses are JSON, names in camelCase, enum values in lower case.
- Every request needs an API key: `Authorization: Bearer ssl_…`. Keys are created in the
  admin interface under *Keys* and have a role:

  | Role | May |
  |---|---|
  | `client` | report events (`POST /api/v1/events`), read the status |
  | `lamp` | fetch the display (`GET /api/v1/lamps`), read the status |

- Use HTTPS – the key is in a header. See the [README](README.md#running-it-on-a-server).

| Method | Path | Role | |
|---|---|---|---|
| POST | [`/api/v1/events`](#post-apiv1events) | client | report a hook event |
| GET | [`/api/v1/lamps`](#get-apiv1lamps) | lamp | the lamp image, long poll |
| GET | [`/api/v1/status`](#get-apiv1status) | client, lamp | state, sessions, stack lights |
| GET | [`/healthz`](#get-healthz) | – | for monitoring |

## POST /api/v1/events

Reports an event of a Claude Code session. What the event does is set in the admin interface
under *Events*.

```http
POST /api/v1/events
Authorization: Bearer ssl_...
Content-Type: application/json

{"event": "Approval", "session": "4f1c2a9e-docs", "host": "DESKTOP"}
```

| Field | | |
|---|---|---|
| `event` | required | `SessionStart`, `UserPromptSubmit`, `Approval`, `Question`, `ToolDone`, `Stop`, `StopFailure`, `ToolFailure`, `SessionEnd`, `Danger` – or `AllOff`, see below. Case does not matter. |
| `session` | required | ID of the session, at most 128 characters. Claude Code passes it to the hook as `session_id`. |
| `host` | optional | name of the computer, at most 64 characters – only for the dashboard |

```json
{"applied":true,"state":"waiting","error":false,"version":1790086577}
```

| Field | |
|---|---|
| `applied` | `false` if the event's rule has a condition that did not hold (e.g. `ToolDone` while the session is not waiting) – then nothing changed |
| `state` | main state the stack light now shows: `ready`, `done`, `working`, `asking`, `waiting`, or `null` without an open session |
| `error` | whether the error overlay is on |
| `version` | version of the lamp image |

**`AllOff`** is not a hook event: it makes the relay forget all sessions of all computers,
and the stack light goes dark until the next event. `session` is not needed for it.

Errors – `400`:

```json
{"error":"unknown event: Nope","events":["SessionStart","UserPromptSubmit","Approval","Question","ToolDone","Stop","StopFailure","ToolFailure","SessionEnd","Danger","AllOff"]}
```

```powershell
$event = @{ event = 'Stop'; session = 'test'; host = $env:COMPUTERNAME } | ConvertTo-Json
Invoke-RestMethod https://relay.example.org/api/v1/events -Method Post -Body $event `
                  -ContentType 'application/json' -Headers @{ Authorization = 'Bearer ssl_...' }
```

## GET /api/v1/lamps

The image of the five lamps, exactly in the form the firmware's
[`POST /api/lamps`](../firmware/API.md#post-apilamps) takes – a stack light can apply
`lamps` as it is.

**Long polling:** `version` is the version the caller already shows. If the relay has a
different one, it answers at once. Otherwise it holds the request until the image changes,
at the latest `wait` seconds, and then answers with the unchanged image.

| Parameter | Default | |
|---|---|---|
| `version` | `0` | version the caller shows; `0` always gets an immediate answer |
| `wait` | long poll duration (25 s) | longest wait in seconds; capped at the long poll duration from *Settings* |

```
GET /api/v1/lamps?version=1790086576&wait=25
Authorization: Bearer ssl_...
```

```json
{"version":1790086577,"state":"waiting","error":false,"lamps":{
  "white":{"on":false,"effect":"pulse","brightness":30,"frequency":0.15,"duty":50},
  "blue":{"on":false,"effect":"pulse","brightness":70,"frequency":0.3,"duty":50},
  "green":{"on":false,"effect":"steady","brightness":45,"frequency":1,"duty":50},
  "orange":{"on":true,"effect":"blink","brightness":40,"frequency":1.2,"duty":55},
  "red":{"on":false,"effect":"steady","brightness":100,"frequency":1,"duty":50}}}
```

All five lamps are always included. Lamps that are off carry the parameters of their state,
so the stack light's web interface shows sensible values.

The version only changes when the image changes, and it starts at the relay's start time in
Unix seconds – after a restart of the relay, a stack light therefore never mistakes the new
count for the one it shows. Callers should only compare for equality.

The stack light sends `X-StackLight-Firmware` and `X-StackLight-Ip` along; the dashboard
shows them.

## GET /api/v1/status

What the relay shows and why. Readable with either role.

```json
{"state":"waiting","error":false,"flash":false,"version":1790086577,
 "sessions":[{"id":"4f1c2a9e","host":"DESKTOP","state":"waiting","error":false,"idleSeconds":0}],
 "stackLights":[{"name":"Desk","remoteAddress":"203.0.113.7","localAddress":"192.168.178.72",
                 "firmware":"1.1.0","lastSeen":"2026-09-22T14:19:04.1559465+00:00",
                 "version":1790086577,"polling":true}],
 "lamps":{ … as with /api/v1/lamps … }}
```

| Field | |
|---|---|
| `flash` | the warning flash is on right now |
| `sessions[].id` | the first 8 characters of the session ID |
| `sessions[].state` | `idle`, `working`, `asking`, `waiting`, `done` – the state of this one session |
| `sessions[].idleSeconds` | seconds since its last event |
| `stackLights[]` | stack lights that have polled since the relay started, one per key |
| `stackLights[].polling` | a request of this stack light is waiting at the relay right now |

`stacklight.ps1 -Event Status` shows the same in relay mode.

## GET /healthz

No key needed. Answers `ok` as plain text – for monitoring or a load balancer.

## Errors

A JSON object with `error` – except for a body that is not valid JSON at all, which
ASP.NET Core rejects with an empty `400`.

| Status | When |
|---|---|
| 400 | invalid event, missing or too long session, body not valid JSON |
| 401 | no key or an unknown key: `{"error":"missing or unknown api key"}` |
| 403 | key with the wrong role: `{"error":"this api key is not allowed here"}` |

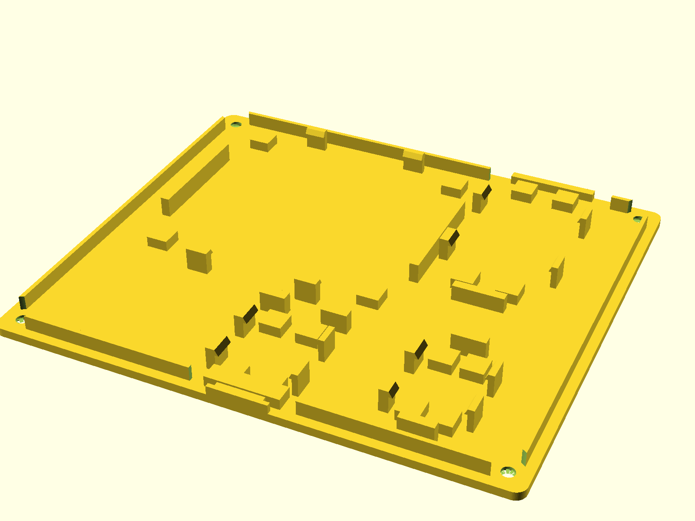
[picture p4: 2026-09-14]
enclosure/OpenSCAD/preview/01_base_iso.png

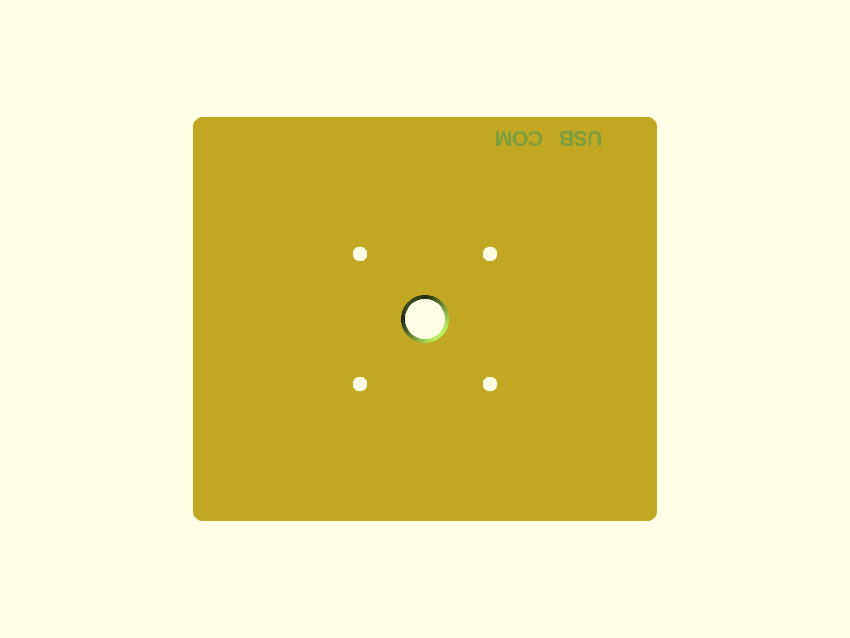
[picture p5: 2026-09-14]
enclosure/OpenSCAD/preview/04_body_lid_top.png

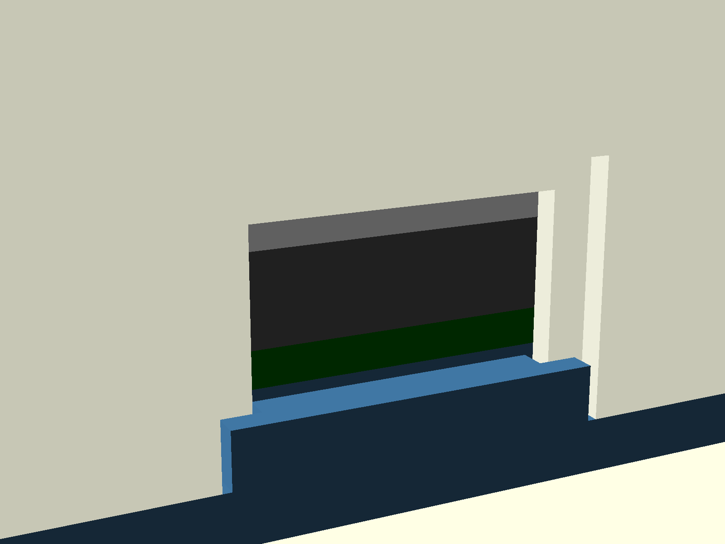
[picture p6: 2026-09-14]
enclosure/OpenSCAD/preview/02_usbc_detail.png

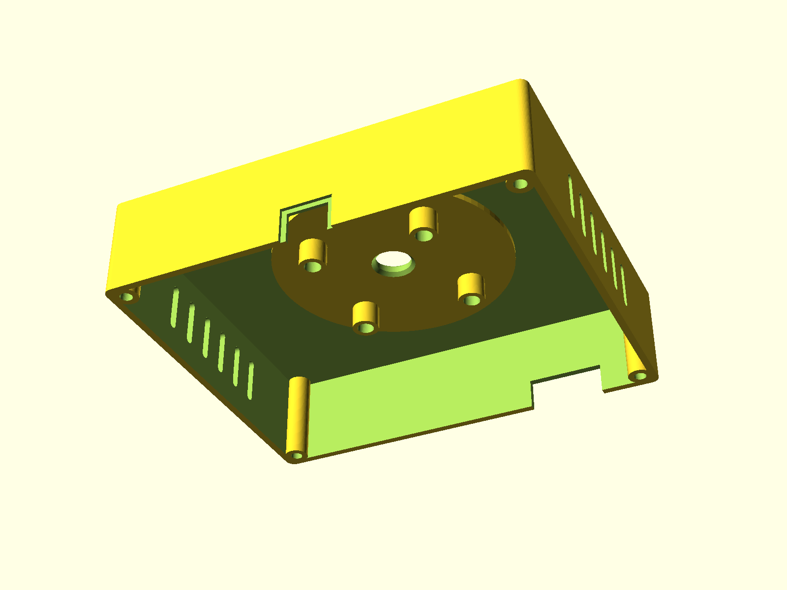
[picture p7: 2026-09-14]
enclosure/OpenSCAD/preview/03_body_inside.png

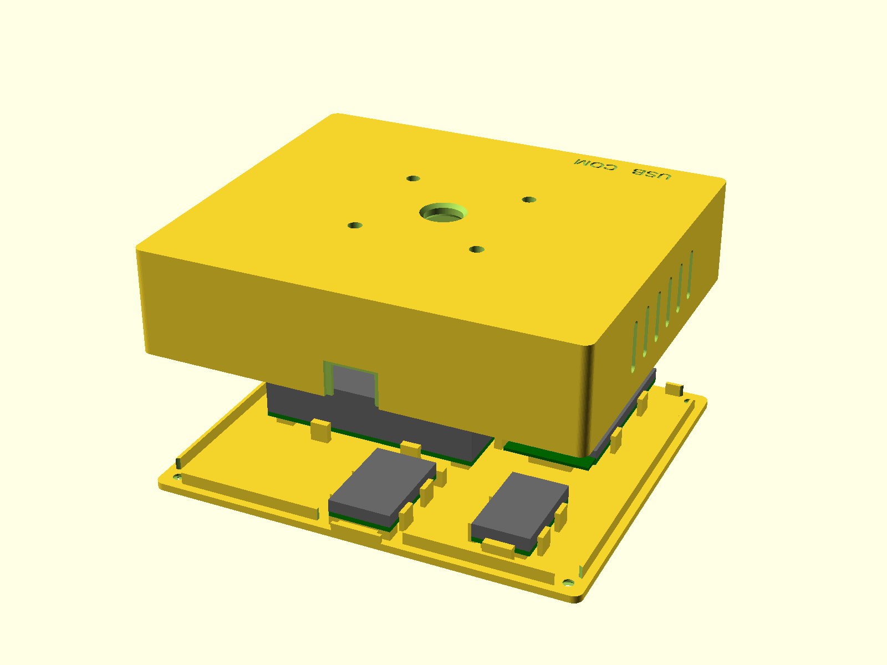
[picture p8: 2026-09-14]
enclosure/OpenSCAD/preview/06_exploded.png

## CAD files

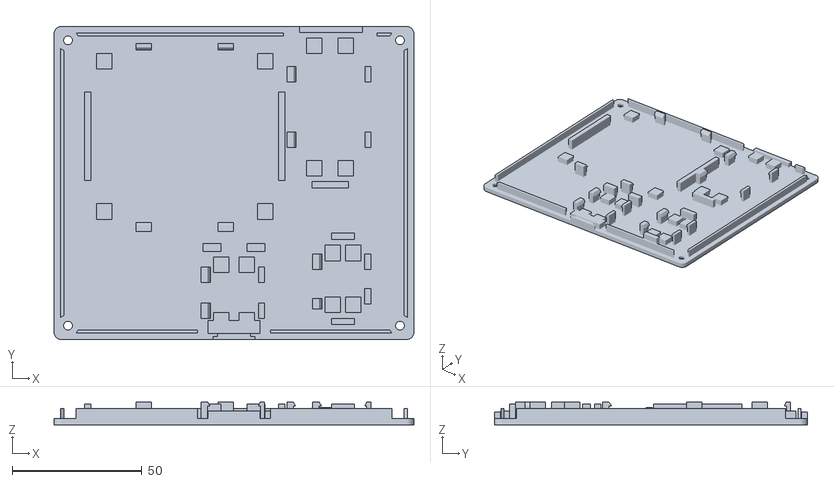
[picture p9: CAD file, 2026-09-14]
enclosure/OpenSCAD/base.stl
138.8 x 120.8 x 8.80

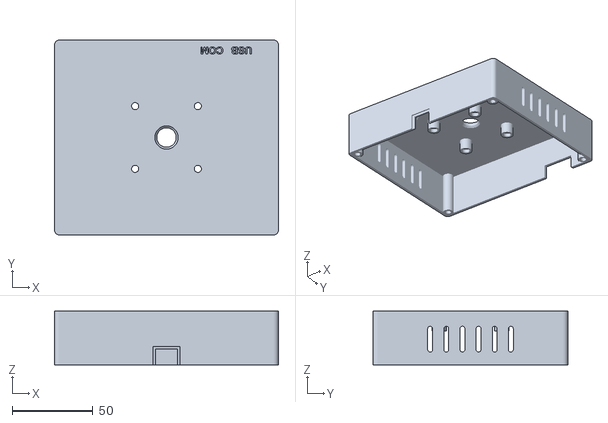
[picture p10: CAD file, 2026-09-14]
enclosure/OpenSCAD/body.stl
138.8 x 120.8 x 33.4

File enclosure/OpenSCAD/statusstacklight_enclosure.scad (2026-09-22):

// ============================================================================
//  StatusStackLight - enclosure for an industrial stack light
//  Stage 1: two parts (main body with integrated lid + removable base plate)
//
//  Contents: ESP32-S3 DevKitC-1 (N16R8), 8-channel MOSFET module, Mini560 buck
//            12V->3.3V, USB-C PD trigger board (requests 12 V)
//
//  Coordinate system (all layout dimensions in "inner coordinates"):
//    x = 0 .. inner_x    left  -> right inner wall
//    y = 0 .. inner_y    front -> back inner wall
//    z = 0               parting plane = top of the base plate (inner floor)
//    z = inner_z         underside of the lid
//
//  Print orientation (support-free):
//    main body:  standing on the lid, opening facing up
//    base plate: flat, inner side (clips) facing up
// ============================================================================

/* [Render] */
// "both" | "body" | "base" | "explosion"
part            = "both";
show_boards     = true;      // boards as ghosts (%) - not included in the STL

$fa = 4;
$fs = 0.35;
eps = 0.01;

// ============================================================================
//  1) PARAMETERS
// ============================================================================

/* [Enclosure basic dimensions] */
inner_x         = 134;    // inner width  (X)
inner_y         = 116;    // inner depth  (Y)
wall            = 2.4;    // wall thickness
base_thickness  = 2.4;    // thickness of the base plate
lid_thickness   = 2.4;    // thickness of the lid
corner_r        = 3.0;    // outer radius of the vertical edges
cable_clearance = 12;     // free height above the tallest assembly
height_override = 0;      // > 0 : set the inner height instead of computing it

/* [Fits] */
clearance       = 0.2;    // general fit clearance (lip, connector collar)
pcb_clearance   = 0.3;    // clearance of the boards in XY
pcb_clearance_z = 0.2;    // clearance below the snap hook
pcb_thickness   = 1.6;    // standard board thickness

/* [Closure base plate <-> main body] */
boss_d          = 8.0;    // outer diameter of the corner bosses
boss_offset     = 3.0;    // axis distance from the inner corner (X and Y)
insert_d        = 4.0;    // hole for the M3 heat-set insert
insert_l        = 6.0;    // insertion depth of the insert
insert_pilot_d  = 2.8;    // clearance hole below the insert
screw_d         = 3.4;    // M3 through hole in the base plate
countersink_d   = 6.2;    // head diameter DIN 7991 (6.0) + clearance
countersink_angle = 90;   // included head angle DIN 7991
countersink_lead = 0.3;   // short cylindrical lead-in at the outer surface:
                          // absorbs the elephant's foot of the first layer and
                          // keeps the head clear of the radius under the head

/* [Centering lip of the base plate] */
lip             = true;
lip_h           = 4.0;
lip_thickness   = 1.2;

/* [Stack light - measured: bolt circle 55 mm, 4 x M4, base 70 mm] */
light_base_d         = 70;    // MEASURED: outer diameter of the stack light base
light_bolt_circle_d  = 55;    // MEASURED
light_screw_n        = 4;     // MEASURED
light_angle_offset   = 45;    // angular position of the first screw [degrees]
light_screw_d        = 4.4;   // M4 through hole in the lid
light_cable_d        = 12;    // central cable feed-through
light_cable_chamfer  = 1.2;   // chamfer as edge protection
light_insert         = true;  // true: M4 heat-set bosses, false: through hole only
light_insert_d       = 5.6;
light_insert_l       = 8.0;
light_boss_d         = 9.0;
light_boss_l         = 10.0;  // length of the bosses below the lid
light_reinforcement  = 2.0;   // additional lid thickness around the flange
// Raised ring around the stack light base. DISABLED: the main body is printed
// standing on the lid, so the ring would be the only thing resting on the
// print bed - the whole remaining lid surface would have hung 1.2 mm in the
// air. The 4 M4 screws on the 55 mm bolt circle centre the flange anyway.
// Only enable if the body is printed differently.
light_centering_ring = false;
light_ring_h         = 1.2;
light_ring_width     = 2.0;

/* [Clip mounting of the boards] */
clip_w                = 6.0;    // width of a clip
clip_hook_h           = 1.6;    // height of the snap hook (also the lead-in chamfer)
clip_thickness_fixed  = 2.5;    // rigid support ledge
clip_hook_fixed       = 1.0;    // overhang of the rigid ledge
clip_thickness_spring = 1.6;    // springy clip
clip_hook_spring      = 0.8;    // overhang of the snap hook
stop_thickness        = 2.5;    // end stop against sliding
stop_above            = 1.0;    // height of the stop above the board top
pad_d                 = 6.0;    // side length of the support pads
pad_inset             = 5.0;    // distance of the pad centre from the board corner

// CONVENTION: all *_h are TOTAL HEIGHTS including the board (as measured with
// calipers across the whole module). *_standoff is the distance of the board
// underside from the parting plane.

/* [Board: 8-channel MOSFET module - measured 68 x 72 mm] */
mosfet_l        = 72;     // longer edge (X)
mosfet_w        = 68;     // shorter edge (Y) - the screw terminals sit here
mosfet_h        = 16;     // MEASURED: total height incl. board and screw terminals
mosfet_standoff = 3.0;
mosfet_pos      = [12, 42];   // terminal edges face the left/right side walls

/* [Board: ESP32-S3 DevKitC-1 N16R8 - MEASURED 57.3 x 28.1 x 1.6 mm] */
mcu_l            = 57.3;  // MEASURED: board length WITHOUT antenna overhang
mcu_w            = 28.1;  // MEASURED
mcu_h            = 5.0;   // total height incl. board (1.6 + 3.4 measured)
mcu_standoff     = 3.0;   // wires are fed into the solder eyes from above, so
                          // the solder joints protrude DOWNWARDS.
mcu_antenna      = 6.3;   // MEASURED: the module's antenna end overhangs the
                          // board edge. It sits at the height of the board
                          // top - the end stop below it must therefore not
                          // stick out above it (mcu_stop_above).
mcu_stop_above   = -0.2;  // 0.2 mm BELOW the board top. Exactly flush (0)
                          // would be ideal, but a tenth of print over-height
                          // would lift the front edge of the board. At -0.2
                          // the stop still engages 1.4 of the 1.6 mm edge.
mcu_pad_inset    = [8, 5];// Support pads further inwards in X than the default:
                          // the solder eyes sit along the long edges, and their
                          // solder joints would otherwise rest on the pads.
mcu_pos          = [90, inner_y - mcu_l];   // rotated by 90 degrees, USB side at
                          // the back wall, antenna pointing forward into the
                          // enclosure. x >= 90 keeps clear of the MOSFET end stop

// Both USB-C ports sit on the same short edge. Measured from the board edge
// that is on the RIGHT inside the enclosure (looking at the back wall from
// behind = from the USB side onto the board, it is the left one).
mcu_usb_edge     = 8.0;   // centre of the "USB" port (native) from the right edge
mcu_com_edge     = 19.5;  // centre of the "COM" port (UART)   from the right edge
mcu_usb_axis     = 1.65;  // axis height of the ports above the board top
mcu_usb_open_w   = 13.5;  // opening width per plug
mcu_usb_open_h   = 7.5;   // opening height

/* [Labels of the USB ports on the lid] */
mcu_text          = true;
mcu_text_size     = 4.5;
mcu_text_spread   = 1.6;  // The port centres are only 11.5 mm apart; at a
                          // legible font size "USB" and "COM" run into each
                          // other. The labels are therefore spread apart by
                          // this factor - left/right remains unambiguous, there
                          // are only two of them.
                          // 1.0 = exactly above the port centres.
mcu_text_depth    = 0.6;  // Engraving depth. The body is printed standing on
                          // the lid, so the text faces the print bed and comes
                          // out clean.
mcu_text_offset   = 4.0;  // centre of the text in front of the back wall's inner edge
mcu_text_rotation = 180;  // 180 = readable from behind, where you plug in
mcu_text_font     = "Liberation Sans:style=Bold";

/* [Board: Mini560 buck converter - MEASURED 30 x 18 x 6 mm] */
buck_l        = 30;       // longer edge
buck_w        = 18;       // shorter edge - the solder pads are here
buck_h        = 6;        // MEASURED: total height incl. board
buck_standoff = 3.0;      // room for the solder joints of the vias
buck_pos      = [100, 6];     // rotated by 90 degrees, front right zone
                              // -> clips grip the long edges, the solder pad
                              //    edges stay freely accessible
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

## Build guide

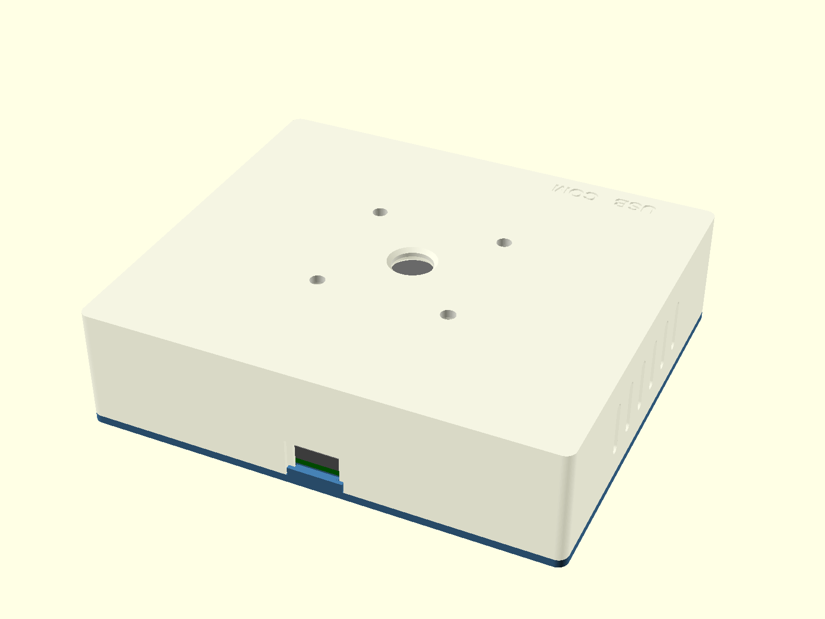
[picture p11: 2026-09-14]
enclosure/OpenSCAD/preview/05_assembled.png

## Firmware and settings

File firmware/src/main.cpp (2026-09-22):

// StatusStackLight - firmware for the 5-lamp stack light.
//
// Structure:
//   lamps.*        LEDC drive and effect engine (own task, core 0)
//   lamp_state.*   state of a lamp, validation and JSON
//   lamp_store.*   last lamp state in NVS, survives restarts
//   wifi_portal.*  credentials, station connection, setup AP with captive portal
//   relay_client.* relay mode: fetches the lamp state from a relay server
//   api_server.*   HTTP routes and the embedded web pages
//
// Pin assignment and everything else that is configurable: include/config.h

#include <Arduino.h>

#include "api_server.h"
#include "config.h"
#include "lamp_store.h"
#include "lamps.h"
#include "relay_client.h"
#include "wifi_portal.h"

namespace {

void printBanner()
{
    Serial.println();
    Serial.println(F("========================================"));
    Serial.printf( "  %s  firmware %s\n", SSL_HOSTNAME, SSL_FIRMWARE);
    Serial.println(F("========================================"));
    Serial.printf( "  Chip      : %s, %u MHz, %u cores\n",
                   ESP.getChipModel(), ESP.getCpuFreqMHz(), ESP.getChipCores());
    Serial.printf( "  Flash     : %u MB\n", ESP.getFlashChipSize() / (1024 * 1024));
    // Shows 0 if board_build.arduino.memory_type does not match the module -
    // with the N16R8 this must be about 8 MB.
    Serial.printf( "  PSRAM     : %u bytes\n", ESP.getPsramSize());
    Serial.printf( "  PWM       : %u Hz, %u bits, active %s\n",
                   PWM_BASE_FREQUENCY, PWM_RESOLUTION_BITS,
                   LAMP_ACTIVE_LOW ? "LOW" : "HIGH");
    Serial.println(F("  Channels  :"));
    for (uint8_t i = 0; i < LAMP_COUNT; i++) {
        Serial.printf("    %u  GPIO %2u  %s\n", i + 1, LAMPS[i].gpio, LAMPS[i].id);
    }
    Serial.println(F("========================================"));
}

}   // namespace

void setup()
{
    // First of all, even before serial output: drive the GPIOs to the off
    // level. After reset they are high-impedance, and with the active-LOW
    // MOSFET module that may well mean "on" - the stack light would flash
    // briefly on every start.
    Lamps::begin();

    Serial.begin(115200);
#if ARDUINO_USB_CDC_ON_BOOT
    // Native USB port: the host has to enumerate the port first, any output
    // before that is lost. With the UART port there is no need to wait.
    const uint32_t start = millis();
    while (!Serial && millis() - start < 3000) {
        delay(10);
    }
#endif
    delay(200);

    printBanner();

    LampStore::load();
    // Before the effect task, otherwise the stored state would flash briefly
    // between its start and Network::begin().
    Lamps::setSystemDisplay(Lamps::SystemDisplay::Connecting);
    Lamps::startEffectTask();
    Network::begin();
    Relay::begin();
    Api::begin();

    Serial.println(F("[start] ready"));
}

void loop()
{
    Network::tick();
    Api::tick();
    LampStore::tick();

    // The lamps do not depend on this loop - they are driven by the effect
    // task on core 0. The short wait only gives the idle task some air.
    delay(2);
}

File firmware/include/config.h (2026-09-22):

// config.h - every value that depends on the hardware, in one place.
//
// If something changes on the stack light (a different lamp, a different
// colour order, a replaced MOSFET module), this is the file to adjust - not
// the rest of the source.

#pragma once

#include <Arduino.h>

// --- Device ----------------------------------------------------------------

#define SSL_HOSTNAME       "StatusStackLight"   // DHCP name and mDNS -> statusstacklight.local
#define SSL_FIRMWARE       "1.1.0"
#define SSL_AP_PREFIX      "StatusStackLight"   // setup AP is called StatusStackLight-XXXX

// --- Lamps -----------------------------------------------------------------

static const uint8_t LAMP_COUNT = 5;

// Switching logic of the MOSFET module.
//
// The module in use is optocoupler-driven and switches active LOW: a GPIO
// pulled to ground turns the lamp on. The inversion happens exactly once,
// when writing the LEDC register (see lamps.cpp); everything above that works
// in "0 = off, 100 = full brightness" throughout.
//
// If testing shows the opposite behaviour (lamps on while nothing drives
// them), setting this to false is all it takes.
static const bool LAMP_ACTIVE_LOW = true;

struct LampChannel {
    uint8_t     gpio;
    const char *id;      // API identifier, lower case
    const char *name;    // display name in the web interface
    const char *color;   // CSS colour of the status dot in the web interface
};

// Order = channel number 1...5 (as in the enclosure README).
//
// VERIFIED: 2026-09-21 against the assembled stack light - this mapping is
// correct.
//
// After rewiring or replacing a lamp, the channel sweep in the web interface
// is the quickest way to check: if a different lamp lights up than the one
// announced, swap the lines here and nothing else.
static const LampChannel LAMPS[LAMP_COUNT] = {
    {  4, "white",  "white",  "#f8fafc" },   // channel 1
    {  5, "blue",   "blue",   "#3b82f6" },   // channel 2
    {  6, "green",  "green",  "#22c55e" },   // channel 3
    {  7, "orange", "orange", "#f59e0b" },   // channel 4
    { 15, "red",    "red",    "#ef4444" },   // channel 5
};

// Display order in the web interface, top to bottom - as indices into
// LAMPS[]. Mirrors the physical stack light (red on top), not the GPIO
// numbers.
static const uint8_t LAMP_UI_ORDER[LAMP_COUNT] = { 4, 3, 2, 1, 0 };

// --- PWM -------------------------------------------------------------------

// 12 bits comfortably cover 101 gamma-corrected brightness steps and still
// allow base frequencies above 20 kHz.
static const uint8_t  PWM_RESOLUTION_BITS = 12;

// Highest register value, i.e. full brightness.
//
// A pitfall that is easy to resolve the wrong way round: at 12 bits, 4095
// would only be a 4095/4096 duty cycle, so the lamp would never be fully on.
// The Arduino core handles this itself - ledcWrite() detects "all bits set"
// and internally writes 4096 = permanently on (see esp32-hal-ledc.c). That is
// why 4095 is correct here and 4096 would be wrong: the value would bypass
// that special case and reach ledc_set_duty() unchecked.
//
// This is exactly what matters for the active-LOW drive: the inversion is
// PWM_MAX - value, and because 0 becomes 4095, the special case applies and
// the lamp is truly dark instead of glowing at 1/4096.
static const uint32_t PWM_MAX             = (1u << PWM_RESOLUTION_BITS) - 1;  // 4095

// Carrier base frequency - fixed, not changeable at runtime.
//
// 1 kHz is the usual compromise for 12 V LED modules: high enough to avoid
// visible flicker, low enough for the MOSFETs to switch cleanly.
//
// There is little headroom anyway: the MOSFET module in use manages about
// 2 kHz. Its gates are charged through a series resistor and discharged
// through a 10 kOhm pull-down, which makes turn-off sluggish - above that, the
// MOSFET spends a growing share of each period in its linear region and heats
// up instead of switching cleanly. The ESP32 would not be the limit: its LEDC
// block derives its clock from 80 MHz, so frequency * 2^resolution <= 80 MHz,
// i.e. up to 19531 Hz at 12 bits.
//
// Not to be confused with the frequency of a lamp effect (FREQUENCY_MIN/MAX
// below) - that one is the blink or pulse rate.
static const uint32_t PWM_BASE_FREQUENCY = 1000;

// Gamma for the brightness curve. 2.2 roughly matches the sensitivity of the
// eye - without it, 50 % looks much brighter than half as bright.
static const float GAMMA = 2.2f;

// --- Limits of the effect parameters ---------------------------------------

static const uint8_t BRIGHTNESS_MIN = 0;
static const uint8_t BRIGHTNESS_MAX = 100;

static const float FREQUENCY_MIN = 0.1f;
static const float FREQUENCY_MAX = 20.0f;

static const uint8_t DUTY_MIN = 1;
static const uint8_t DUTY_MAX = 99;

// --- Defaults --------------------------------------------------------------
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

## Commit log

2026-09-06 Initialer Stand: StatusStackLight-Gehaeuse (OpenSCAD)
    Zweiteiliges, parametrisches Gehaeuse fuer die Signalsaeule:
    Hauptkoerper mit integriertem Deckel + abnehmbare Bodenplatte,
    die die gesamte Elektronik (NodeMCU V3, 8-Kanal-MOSFET, LM2596,
    USB-C-PD-Trigger) schraubenlos in Clipsen traegt.
    Enthaelt Modellquelle, exportierte STLs und Rendering-Vorschauen.
    Claude-Session: https://claude.ai/code/session_017zA16PBAW3H3zFhLWGLJ1e
    [boden.stl, body.stl, statusstacklight_gehaeuse.scad]
2026-09-06 Gemessene Masse eingetragen: MOSFET-Hoehe, PD-Board, Saeulenfuss
    - mosfet_h 15 -> 16 (gemessen, inkl. Schraubklemmen)
    => Innenhoehe 30 -> 31 mm, Aussenmass 138,8 x 120,8 x 35,8 mm
    - pd_l 31 -> 30 (PD-Triggerboard ist 30 x 20 mm)
    - saeule_fuss_d = 70 bestaetigt
    - neu: usbc_ueberstand = 1,0 - die Buchse steht 1 mm ueber die
    Platinenkante vor und taucht in den Wanddurchbruch ein. Damit
    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
    [boden.stl, body.stl, statusstacklight_gehaeuse.scad]
2026-09-06 Mini560 statt LM2596, Render-Skript, neue Previews
    Buck-Converter:
    - Mini560, gemessen 30 x 18 x 6 mm (vorher LM2596 43 x 21 x 14)
    13 mm kuerzer, 8 mm flacher; belegt jetzt x 100..118, y 6..36.
    Die Clipse greifen weiterhin die langen Kanten, die Loetpad-Kanten
    (Schmalseiten) bleiben frei zugaenglich.
    Konvention der Bauhoehen vereinheitlicht:
    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
    [boden.stl, body.stl, statusstacklight_gehaeuse.scad]
2026-09-06 Bodenschrauben: kegelige Senkung statt Flachsenkung
    Die Senkungen waren zylindrische Flachsenkungen (d 6,2 x 1,7 tief) - ein
    DIN-7991-Senkkopf haette darin nur auf der oberen Kante aufgelegen statt
    flaechig zu tragen.
    Jetzt ein echter 90-Grad-Kegel:
    - senkung_t entfaellt; die Tiefe folgt aus senkung_winkel und senkung_d
    (1,4 mm Kegel), sonst passt der Kegel nicht zum Schraubenkopf.
    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
    [boden.stl, body.stl, statusstacklight_gehaeuse.scad]
2026-09-06 Deckel plan: Zentrierring abgeschaltet; NodeMCU-Unterbau festgelegt
    Zentrierring:
    - Der Hauptkoerper wird auf dem Deckel stehend gedruckt. Der erhabene Ring
    waere dann das Einzige gewesen, was auf dem Druckbett aufliegt - die
    gesamte restliche Deckelflaeche haette 1,2 mm in der Luft gehangen und
    vollflaechig Stuetzen gebraucht.
    - saeule_zentrierring = false. Der Parameter bleibt im Modell, mit einem
    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
    [boden.stl, body.stl, statusstacklight_gehaeuse.scad]
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2026-09-14 PD-Anschlagrippe mittig geteilt: Kabelausgang fuer die Loetaugen
    Die Loetaugen des USB-C-PD-Boards sitzen hinten mittig - die durchgehende
    Anschlagrippe haette die Kabel eingesperrt.
    - neu usbc_rippe_luecke = 10: mittige Luecke in der Rippe. Es bleiben zwei
    Segmente von je 7 mm an den hinteren Platinenecken.
    - Der Kraftfluss verbessert sich dadurch: die Einsteckkraft geht in die
    Platinenecken statt in die Mitte, die Platine wird nicht mehr auf Biegung
    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
    [boden.stl, body.stl, statusstacklight_gehaeuse.scad]
2026-09-14 Mini560: vordere linke Auflageleiste versetzt und schmaler
    Auf der linken Platinenkante des Mini560 (Draufsicht, USB-C-Eingang unten)
    sitzt ein Bauteil buendig mit der Kante - die Leiste griff dort nicht und
    musste am gedruckten Teil mit dem Dremel nachgearbeitet werden.
    - buck_klemm_vl_versatz = 3.0: die Leiste rueckt von y=14.4 auf y=11.4.
    - buck_klemm_vl_breite = 4.0: dort liegt die Loetstelle des Plus-Eingangs,
    deshalb 4 statt 6 mm breit. Zur Platinenvorderkante bleiben 3,4 mm.
    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
    [boden.stl, body.stl, statusstacklight_gehaeuse.scad]
2026-09-14 README: pd_l auf 31,5 nachgezogen
    Der Wert wurde in 8be9675 im Modell korrigiert, die README stand noch
    auf 30 - in der Massliste und in der Layouttabelle.
    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
2026-09-14 USB-C-Steckerkragen: eigene, groessere Passung
    Der Kragen bekam bisher das allgemeine spiel = 0,2 mm. Das war im Druck
    eine Presspassung und musste nachgeschliffen werden.
    Ursache: links und rechts des Wanddurchbruchs haengen zwei nur 1,75 mm
    schmale Wandzungen nach unten (der Absatz zwischen Durchbruch 13,5 und
    Aussenansenkung 17). Die fassen in die Kerben zwischen Zunge und Stufe des
    Kragens - und weil beide Kragenteile von derselben 0,2 mm zehren, bleibt an
    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
    [boden.stl, body.stl, statusstacklight_gehaeuse.scad]
2026-09-14 ESP32-S3 statt NodeMCU V3: Footprint, zwei USB-C, Deckelbeschriftung
    Der ESP8266 weicht einem ESP32-S3 DevKitC-1 N16R8. Alle nodemcu_*- und
    microusb_*-Variablen heissen jetzt generisch mcu_*.
    Platine (gemessen 57,3 x 28,1 x 1,6):
    - mcu_pos rueckt automatisch an die Rueckwand (innen_y - mcu_l).
    - mcu_h = 5,0 als Gesamthoehe inkl. Platine (1,6 + 3,4 gemessen). Damit
    faellt die bisherige grosszuegige Annahme von 14 mm weg; die Innenhoehe
    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
    [boden.stl, body.stl, statusstacklight_gehaeuse.scad]
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2026-09-21 Rahmung als Erst-Inbetriebnahme entfernt, Diagnose bleibt
    Der Aufbau laeuft, die Verkabelung ist geprueft. Damit war ein guter Teil der
    Doku ueberholt: die README fuehrte eine Abnahme-Checkliste ("direkt nach dem
    Reset muessen alle fuenf GPIOs auf 3,3 V liegen", Nachglimmen im Dunkeln
    gegenpruefen), und quer durch den Quelltext begruendeten Kommentare
    Entscheidungen mit "beim Verkabelungstest". Beides beschreibt einen Zustand,
    den es nicht mehr gibt.
    Geloescht ist die Einmal-Pruefung aber nicht, sondern umgeschrieben: aus
    "Verkabelung pruefen" wird "Diagnose", und statt der Reihenfolge, in der man
    ein neues Geraet abnimmt, steht dort jetzt, woran man einen einzelnen
    auffaelligen Kanal erken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
    [config.h]
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2026-09-22 Versorgung des ESP32: Mini560 liefert 3,3 V an den 3V3-Pin
    Die Doku ging noch von 12 V -> 5 V am 5V-Pin aus. Nachgemessen: verbaut
    ist die 3,3-V-Variante des Mini560, gelötet an den 3V3-Pin. README und
    SCAD-Kopf korrigiert; der Kopf nannte außerdem noch NodeMCU und LM2596.
    In der Montagereihenfolge steht jetzt, warum man zum Flashen per USB die
    3,3-V-Leitung besser trennt.
    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
    [statusstacklight_gehaeuse.scad]
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2026-09-22 Show a photo of the stack light in the README
    Replace the enclosure rendering at the top of the README with a photo of
    the assembled stack light (docs/images/stacklight.jpg). The JPEG carries
    no EXIF data, only the Display P3 colour profile.
    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
2026-09-22 Add relay server skeleton with display logic
    New fourth part relay/: an ASP.NET Core service the stack light will poll
    and the Claude Code hooks will report to, so light and computer no longer
    need to share a network.
    This first step holds the domain logic, a C# port of Get-MainState and
    Get-Lamps from claude-code/stacklight.ps1: sessions from any number of
    computers, priority of the main states, error latch, done-to-ready
    fallback, stale sessions and the warning flash. Events map to session
    states through configurable rules; the factory defaults in Defaults.cs
    reproduce the script exactly. The lamp image carries a version that only
    changes with the image, for long polling.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
2026-09-22 Add relay HTTP API with API keys and long polling
    - POST /api/v1/events for hook scripts, GET /api/v1/lamps (long poll) for
    stack lights, GET /api/v1/status, /healthz.
    - API keys with a role (lamp or client), shown once, stored as SHA-256
    hash, checked from memory; last use is written at most once a minute.
    - Configuration and keys in SQLite via EF Core; config sections stored as
    JSON documents, missing states or events filled from the defaults.
    - Cookie login prepared for the admin interface; the password is only set
    on the server with "set-password", never over the web.
    - Timer service replaces the script's straggler process for done-to-ready,
    stale sessions and the end of the wa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
2026-09-22 Add relay admin interface
    Razor Pages behind a cookie login (rate limited):
    - Dashboard: live stack light image, open sessions, polling stack lights,
    test events for a dedicated session, all off, connection hints.
    - Display: per state which lamps light and how (effect, brightness,
    frequency, duty), with a live preview using the firmware's formulas.
    - Events: per hook event the session state, the error flag, an optional
    "only if the session is" condition and the warning flash.
    - Settings: priority of the main states and the timings.
    - Keys: create (shown once), rename, delete.
    Each section can be reset to the factory defaults. Forms use the
    invariant culture so decimal values survive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
2026-09-22 Add relay mode to the hook script
    With STACKLIGHT_RELAY_URL and STACKLIGHT_RELAY_KEY set (or -RelayUrl and
    -RelayKey), stacklight.ps1 reports each event to the relay instead of
    switching the stack light. The hooks stay unchanged; without the
    variables the script works in LAN mode as before.
    The dangerous-command check stays local, so no command text leaves the
    computer, and so does the session bookkeeping for the ToolDone shortcut.
    No mutex and no straggler in relay mode; -Event Status shows the relay's
    view.
    Relay: the timer now ticks every 250 ms, so the warning flash ends close
    to its set duration, and the default URL binds IPv6 as well - "localhost"
    otherwise waited two seconds for ::1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
2026-09-22 Add relay mode to the firmware
    The stack light can now fetch its state from the relay instead of being
    switched over the local API (firmware 1.1.0):
    - relay_client: long polling in its own task on core 1 with the version
    of the image shown; backoff 2...30 s on failures; a poll started under
    older settings is discarded, so switching relay mode off takes effect
    at once.
    - HTTP and HTTPS; for HTTPS the Let's Encrypt roots ISRG Root X1 and X2
    are embedded, since core 2.0.x ships no certificate bundle.
    - New system display: red pulsing slowly and dimly after a minute without
    contact to the relay. Boot display and portal take precedence.
    - Lamps::applyBatch validates and applies several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
    [api_server.cpp, config.h, lamps.cpp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]
2026-09-22 Add relay deployment files and documentation
    - relay/README.md: how it works, admin interface, trying it locally,
    running it on a Linux server (self-contained publish, systemd, nginx
    with certbot, set-password), configuration, backup, development.
    - relay/API.md: events, long poll, status, errors - with real responses.
    - deploy/: hardened systemd unit and an nginx example with the timeouts
    long polling needs, including a sub-path variant.
    - Root README: the relay as the fourth part.
    Relay: waiting long polls are answered at once on shutdown instead of
    holding up the stop for up to 25 s.
    Firmware: a redirect from the relay (http:// sent on to https:// by
    nginx) is reported with the hi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
    [relay_client.cpp]
2026-09-22 Add the PostToolUseFailure hook to the example configuration
    The script and the relay already handled -Event ToolFailure (red, latched
    until the next prompt), but hooks.example.json never wired it up. The
    README now lists the hook and suggests trying it out first: tool calls
    fail often in normal work, and a red light that is always on gets ignored.
    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
2026-09-22 Leave PostToolUseFailure unwired on purpose
    Reverts 8207f36. Failed tool calls are part of normal work and Claude
    usually recovers by itself; red for each of them would come so often that
    it gets ignored - also in the one case that counts. Red stays reserved
    for a response that ended in an error and for the warning flash. The
    README now says so, so the hook does not get added again by accident.
    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
